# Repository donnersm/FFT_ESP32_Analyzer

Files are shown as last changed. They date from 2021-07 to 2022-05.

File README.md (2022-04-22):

** important update: If your display doesn't respond well to the microphone input, you can adjust resistor R10,( The lower the value, the better the amplification) infact,you can remove it and replace it by a wire or some soldering tin. I did it on my prototype and result is amazing

Also: There are issues with the I2S_DMA_Matric library in version 2.07 ( and maybe above but have not tested) if you experiencing issues with reboot and I2S DMA ERROR.. change this library to version 2.05 (sure to work)

# FFT_ESP32_Analyzer
Spectrum analyzer 8-64channels FFT

8-64 Channel FFT Spectrum Analyzer
-	Line in Audio
-	Mic in Audio
-	8,16,24,32 or 64 channels
-	Different patterns and colors
-	Adjustable Peak Delay time
-	Selectable input filter
-	Auto change of patterns every few seconds ( can be set to on/off)
-	Based on ESP32
-	PCB available with onboard pre-amplifier and connector or HUB75 Displays
-	Can drive ledstrip like WS2812 and similar 
-	Can drive series of HUB75€ Panels
-	Adjustable overall brightness
PCB available with SMD components pre-assembled. You will only need to add the ESP32 board and the connectors / opamp and sockets.
Schematic and PCB layout and gerber files( PCB production files) available
Work in progress:
Future firmware update will include:
-	Smooth LED transition as the LEDS are so fast it will follow the datastream. I want to implement a sort of afterglow on each led when it turns of. That will moving bars will look less hectic.
-	Web interface, I would like to output data on wifi to visualize the spectrum live on a webbrowser. Although technically this already has been done, the challenge will be the use of the ADC's at the same time. Those of you who know the architecture of the ESP32 will now what I mean.
-	Changing the number of bands runtime unlike now it is done before compiling and can only be changed by uploading the firmware with changed parameters.
-	Elaborate and automize the calibration modes.

See Manual4.0.pdf for more details and information

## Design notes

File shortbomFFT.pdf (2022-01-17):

## Page | 9

## 5.1.3. PCB Part list main PCB

## The complete part list for the main PCB is here:

ID | Name | Designator | Footprint | Quantity | Manufacturer Part | Manufacturer | Supplier | Supplier Part
1 | 470uF | C1 | CAP‐SMD_BD8.0‐L8.3‐W8.3‐RD | 1 | VZH471M1CTR‐0810 | LELON | LCSC | C164069
2 | 100nF | C2,C3 | C0805 | 2 | CC0805KRX7R9BB104 | YAGEO | LCSC | C49678
3 | 470uF | C4,C5,C6 | CAP‐SMD_BD8.0‐L8.3‐W8.3‐RD | 3 | VZH471M1CTR‐0810 | LELON | LCSC | C164069
4 | 100nF | C8 | C0805 | 1 | CC0805KRX7R9BB104 | YAGEO | LCSC | C49678
5 | 1uF | C7,C11 | C0805 | 2 | CL21B105KBFNNNE | SAMSUNG | LCSC | C28323
6 | 10nF | C9,C14 | C0805 | 2 | CL21B103KBANNNC | SAMSUNG | LCSC | C1710
7 | 220nF | C10,C15 | C0805 | 2 | CL21B224KBFNNNE | SAMSUNG | LCSC | C5378
8 | 100uF | C12,C16 | C1206 | 2 | 1206X107M6R3NT | FH | LCSC | C178304
9 | 100pf | C13 | C0805 | 1 | CL21C101JBANNNC | SAMSUNG | LCSC | C1790
10 | 22041021 | CN1 | CONN‐TH_22041021 | 1 | 22041021 | MOLEX | LCSC | C185215
11 | 22041051 | CN2,CN3 | CONN‐TH_22041051 | 2 | 22041051 | MOLEX | LCSC | C505160
12 | 22041031 | CN4,P5 | CONN‐TH_3P‐P2.54_22041031 | 2 | 22041031 | MOLEX | LCSC | C293437
13 | Header‐Male‐2.54_1x8 | CN5 | HDR‐TH_8P‐P2.54‐V‐M | 1 | 210S‐1*8P L=11.6MMGold‐plated black | Ckmtw | LCSC | C124381
14 | 22041041 | CN6 | CONN‐TH_22041041 | 1 | 22041041 | MOLEX | LCSC | C185196
15 | ES5JB | D1,D2 | SMB_L4.6‐W3.6‐LS5.3‐RD | 2 | ES5JB | Shandong Jingdao Microelectronics | LCSC | C123908
16 | | P1,P3 | | 2 | WJ500V‐5.08‐2P‐14‐00A | ReliaPro | LCSC | C8465
17 | HDR‐IDC‐2.54‐2X8P | P2 | IDC‐TH_16P‐P2.54_C3406 | 1 | IDC Box 2.54mm 16P Straight | BOOMELE | LCSC | C3406
18 | WJ500V‐5.08‐3P‐14‐00A | P4 | CONN‐TH_3P‐P5.00_WJ500V‐5.08‐3P | 1 | WJ500V‐5.08‐3P‐14‐00A | ReliaPro | LCSC | C72334
19 | 470 | R1,R2 | R0805 | 2 | 0805W8F4700T5E | UniOhm | LCSC | C17710
20 | 470K | R5 | R0805 | 1 | 0805W8F4703T5E | UniOhm | LCSC | C17709
21 | 6.8K | R11 | R0805 | 1 | 0805W8F6801T5E | UniOhm | LCSC | C17772
22 | 10K | R13,R17 | RES‐TH_RK09D1130C2P | 2 | RK09D1130C2P | ALPS Electric | LCSC | C361173
23 | 1K | R15 | R0805 | 1 | 0805W8F1001T5E | UniOhm | LCSC | C17513
24 | 5.1K | R3,R7,R8,R16,R21 | R0805 | 5 | 0805W8F5101T5E | UniOhm | LCSC | C27834
25 | 56K | R19 | R0805 | 1 | 0805W8F5602T5E | UniOhm | LCSC | C17756
26 | 820 | R6,R20 | R0805 | 2 | AC0805FR‐07820RL | YAGEO | LCSC | C229015
27 | 10K | R22,R25 | R0805 | 2 | RNCS0805BKE10K0 | Stackpole Elec | LCSC | C346681
28 | 10K | R9,R23 | RES‐ADJ‐TH_3296W | 2 | 3296W‐1‐103LF | BOURNS | LCSC | C34846
29 | 27K | R10,R24 | R0805 | 2 | 0805W8F2702T5E | UniOhm | LCSC | C17593
30 | 100K | R4,R12,R14,R18,R26,R27 | R0805 | 6 | 0805W8F1003T5E | UniOhm | LCSC | C17407
31 | TC‐1102‐C‐J‐B | SW1,SW2 | KEY‐TH_4P‐L6.0‐W6.0‐P4.50‐LS6.5 | 2 | TC‐1102‐C‐J‐B | XKB Enterprise | LCSC | C381016
32 | 5TR4A 250V | U1 | FUSE‐TH_BD8.5‐P5.08‐D1.0 | 1 | 5TR4A 250V | XC Elec(Shenzhen) | LCSC | C140489
33 | AMS1084CM‐5.0 | U2 | TO‐263‐3_L8.6‐W10.2‐P2.54‐LS14.4‐TL | 1 | AMS1084CM‐5.0 | AMS | LCSC | C56105
34 | ESP32_DevKit_V1_DOIT | U3 | ESP32_DEVKIT_V1_DOIT | 1
35 | 5002 | U4,U6 | TEST‐TH_BD2.54‐P1.39 | 2 | 5002 | Keystone | LCSC | C238123
36 | LM358N | U5 | PDIP‐8_L10.2‐W5.9‐P2.54‐LS7.6‐BL | 1 | LM358N | Texas Instruments | LCSC | C83405
37 | 5001 | U8 | TEST‐TH_BD2.54‐P1.39 | 1 | 5001 | Keystone | LCSC | C238122
38 | 5003 | U9,U10 | TEST‐TH_BD2.54‐P1.39 | 2 | 5003 | Keystone | LCSC | C238124

REMEMBER: MOST COMPONENTS ARE STANDARD COMPONENTS AND CAN BE REPLACED BY OTHER TYPE/ BRAND ETC. USE THIS LIST AS A GUIDE NOT AS AN ABSOLUTE MUST! Everything in red is not assembled when you buy the version with Pre‐assembled SMD. Pos. 35,37,38,13 are optional. Also you should mount U5 and U3 on a socket!
Short bom

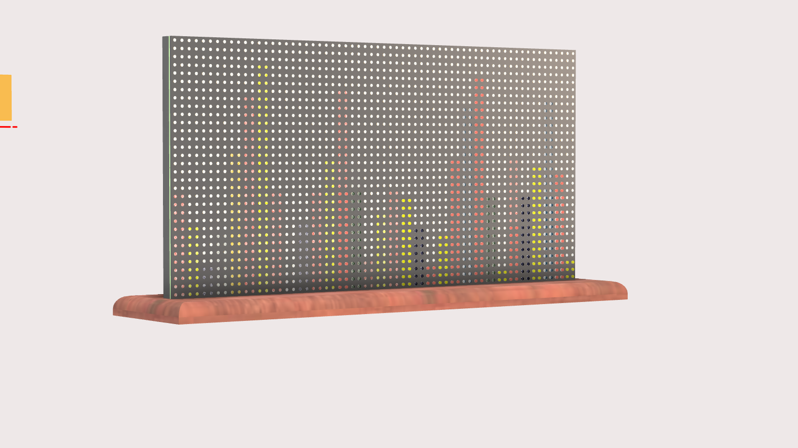
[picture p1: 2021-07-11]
3D Design/Spectrum op plank v7.png

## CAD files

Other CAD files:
3D Design/FFT4.1 on Board.f3d

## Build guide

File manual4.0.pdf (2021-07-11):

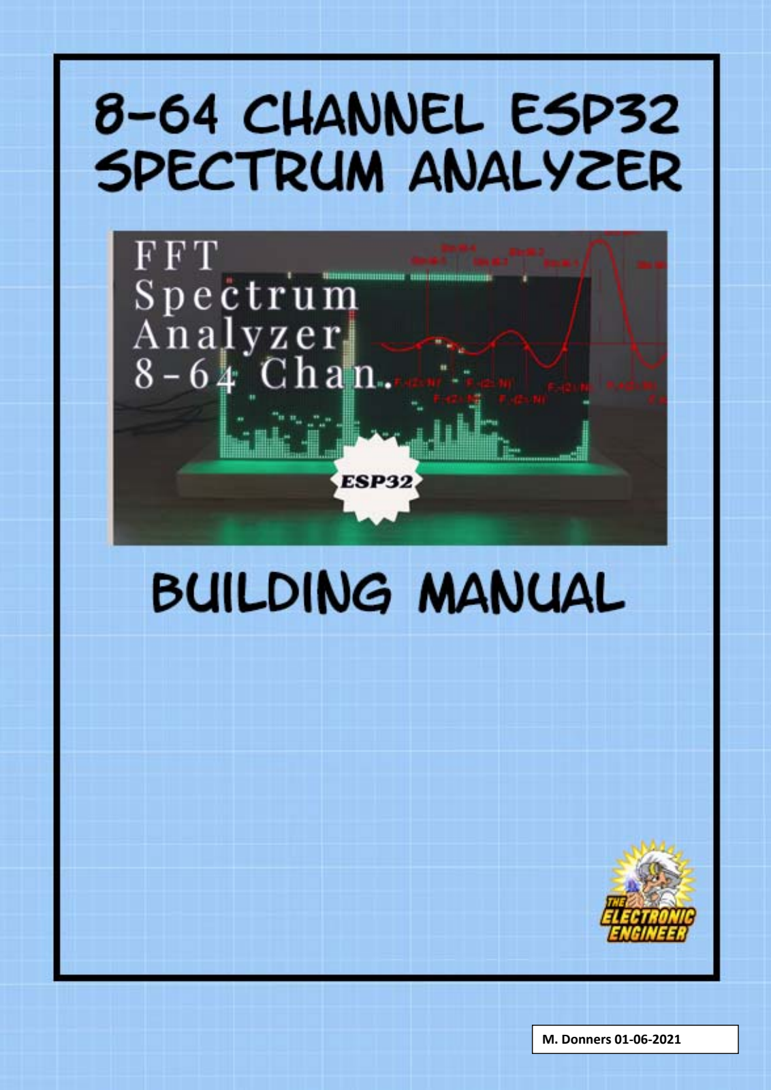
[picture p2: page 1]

M. Donners 01‐06‐2021

## Table of Contents

M Donners Document version 1.0 July 2021

## 1. Disclaimer and safety

I, Mark Donners, The Electronics Engineer, may or may not endorse various Do‐It‐Yourself (DIY) projects and all DIY projects are purely “at your own risk”. As with any DIY project, unfamiliarity with the tools and process can be dangerous. Posts should be construed as theoretical advice only.

If you are at all uncomfortable or inexperienced working on these projects (especially but not limited to electronics and mechanical), please reconsider doing the job yourself. It is very possible (but not likely) on any DIY project to damage belongings or void your property insurance, create a hazardous condition, or harm or even kill yourself or others.

I will not be held responsible for any injury due to the misuse or misunderstanding of any DIY project.

By using the information provided by me, (Website, YouTube, Facebook and other social media), you agree to indemnify me, affiliates, subsidiaries and their related companies for any and all claims, damages, losses and causes of action arising out of your breach or alleged breach of this agreement(disclaimer).

The materials on this site are distributed “as is” and appear on the site without express or implied warranties of any kind, except those required by the relevant legislation. In particular, I make no warranty as to the accuracy, quality, completeness or applicability of the information provided.

The information provided is for entertainment and promotional purposes only. You may not rely on any information and opinions expressed in it for any other purpose.

Disclaimer short version:

This is a DIY project, use any provided information and/or materials at your own risk! I am not responsible for what you do with it!

## 2. About this project

This document is related to the FFT Spectrum analyser. It has 8, 16,24,32 or even 64 frequency bins (channels) and you might be able to double that number of bins if you modify the firmware.

The pcb is capable of driving a matrix of pixelleds ( WS2812 or led matrix) or you can connect one or more HUB75E displays but you will have to make a choice which one to use and adjust the parameters in the settings accordingly.

You can connect your audio signal by using the audio input or you can use the microphone input to connect a small condenser microphone. Although using the microphone will limit the frequency response because of its limitations.

The input sensitivity is automated and it will adjust to the levels off the input. You can adjust brightness and peak hold time. When it does not receive any input signal, after a while, it will go to fire mode in which some leds/display will light up like a fire.

I used two HUB75E panels for my prototype as I mounted them on a wooden stand. The PCB was mounted to the back of the display. I designed a PCB for the electronics. The PCB can be purchased at my Tindie web shop. The firmware (Arduino Sketch ) is open source and you can modify it to your needs.

## 3. Operation

You can use the microphone in to connect a small condenser microphone or you can connect your audio device to the line input connectors.

Mode button
The mode button has 3 functions:

Short press: change pattern(mode), there are 12 available patterns from which the last one is a fire screensaver.

Fast double press: Change the calibration filter. You can choose from none, white, pink or brown noise. Each mode will manipulate the output data accordingly.

For white noise, a white noise sound source of 1Vpp was connected to the input and all the output values where measured. The measured values where recalculated and copied to the filter database. When calibrated, all the output values are almost equil in amplitude when the mentioned source is connected. I did the same for pink and brown noise.

Long press: Press and hold for a few seconds to enable/disable the automode. When automode is enabled, the patterns will change every few seconds.

Reset Button
This will reset the microcontroller. However, It will not reset the led strips.

Brightness Potmeter
You can use this to adjust the overall brightness of all leds / display. WARNING:Make sure you use a power supply to match the current for the brightness that you set. For sure, the ESP32 onboard regulator can not handle all leds at full brightness. It is best to use an external powersupply that can handle 4 to 6 A. If you are using the USB cable that is connected to the ESP32, you might end up with a burning sensation coming from the ESP32 Board.

Peak Delay Potmeter
You can use this to adjust the time it takes for a peak to fall down to the stack

Serial Monitor
If you enabled the DEBUG mode in the firmware of by activating and completing the hardware test, the serial monitor (USB) will output information.

4. Tools needed.

You will be working with low voltage and you should know your way around basic electronics. Using the wrong voltage or polarity might not kill you but it will destroy your project in an instance!

Being successful in building this device requires some adequate skills and tools. You should be able to solder small components on a PCB which will require a soldering station with a small tip as you will be handling components like 0805 sized although small, if you have a steady hand, you should be able to solder them onto the board. If this is beyond your possibilities, then you should buy the pcb version that has all SMD components pre‐installed.

Furthermore, you will be programming the microcontroller by using the Arduino IDE environment. Although the steps to do so will be described in this document, it is advisable for you to get to know this Arduino software.

And yes, you will need some basic tools like a screwdriver

## 5. Hardware

## 5.1. Main PCB

The pcb is available at my Tindie store here:

https://www.tindie.com/products/markdonners/pcb‐8‐64‐channel‐fft‐spectrum‐analyzer/

The PCB has all SMD components pre‐installed and all you nee to add is the ESP32 board and a hand full of small components.

Shipping is only possible within the EU because shipping to other countries will involve import Tax, declarations of conformity and other complicated stuff. Nobody is looking for that kind of complicated formalities or import tax upon receiving the goods. I do make some exceptions for USA and UK. If you are a resident of a country that I don’t ship to, you can always order a pcb directly from a PCB supplier near you. The Gerber productions files you need for that are available for download, although it might be more expensive than what you are hoping for. If you need 1 or 2 PCB’s, a Tindie order is the cheapest way to go.

My shipping policy might change over time so always check the Tindie store to see if I am shipping to your country. ADDITION: I have successfully shipped to UK, USA and other non‐EU countries but handling the tax, import fee and so on is on you! Check out the Tindie store to see what is possible for your country.

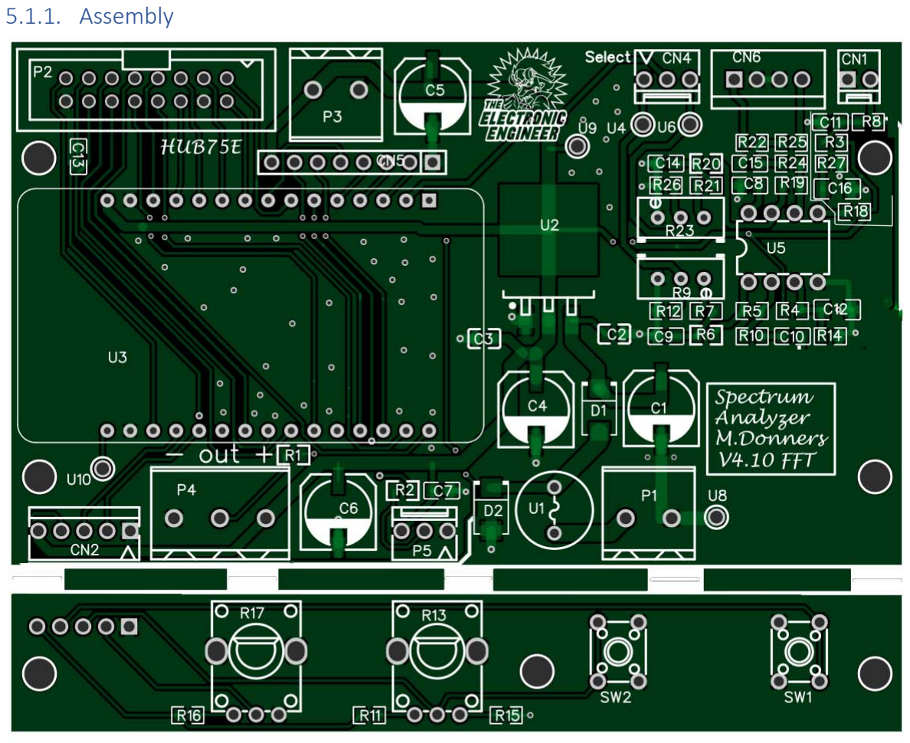
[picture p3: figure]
5.1.1. Assembly

Assembly notes:

Start with all small SMD components. The last smd components to be mounted are C1,C4,C5 and C6.

Use IC Sockets or Female headers to mount Ic's (U5), ESP32 board (U3).It is also wise to use a socket for the fuse (U1). Solder all the connectors last. You don’t need to solder the connectors that you don't need. Connector CN5 is only needed if you are planning to use those extra pins but if not, you can leave it out. Connectors P2 and P3 are to be used to connect a HUB75E panel while connector P4 is used for connecting ledstrips or a pixel‐led based matrix. You can decide to leave out the connectors you do not need.

C13 has been added to compensate Latency Timing for some versions of the board I run into in a shipment from May 2021.

Here are some links for some of the used components. A more detailed list of components is available on one of the following pages of this document.

Microphone
A used a simple electret microphone like this one:

https://nl.aliexpress.com/item/32961327636.html?spm=a2g0o.productlist.0.0.40156749GH0jMh&algo_pvid=b3873d4e‐2d66‐4844‐b423‐45a81e07bc15&algo_expid=b3873d4e‐2d66‐4844‐b423‐ 45a81e07bc15‐
0&btsid=2100bdd516132465203027466e5419&ws_ab_test=searchweb0_0,searchweb201602_,sear chweb201603_

Power Supply

You will be needing a power supply of DC 12V that can handle 4 to 6A. ( Current depends on the number of panels or leds you are planning to connect. Make sure your power supply is stable and doesn’t have noise on the output.

You'll also need some connectors for audio and power, a toggle switch to select the audio input and some wire to connect all. Regarding the power to the leds, use a wire that can handle a current of 4A Depending on what you planning, thinner wire can do the job as well.

Also, you'll need to order a few meter of Pixel Ledstrip WS2812. Make sure you order the one that works with your design. (number of pixels per meter varies) I used 74Leds/meter version.

Or are you planning to use one or more HUB75 led panels? I used 2 64*64 panels to create a matrix of 64 pixels height and 128 pixels width.

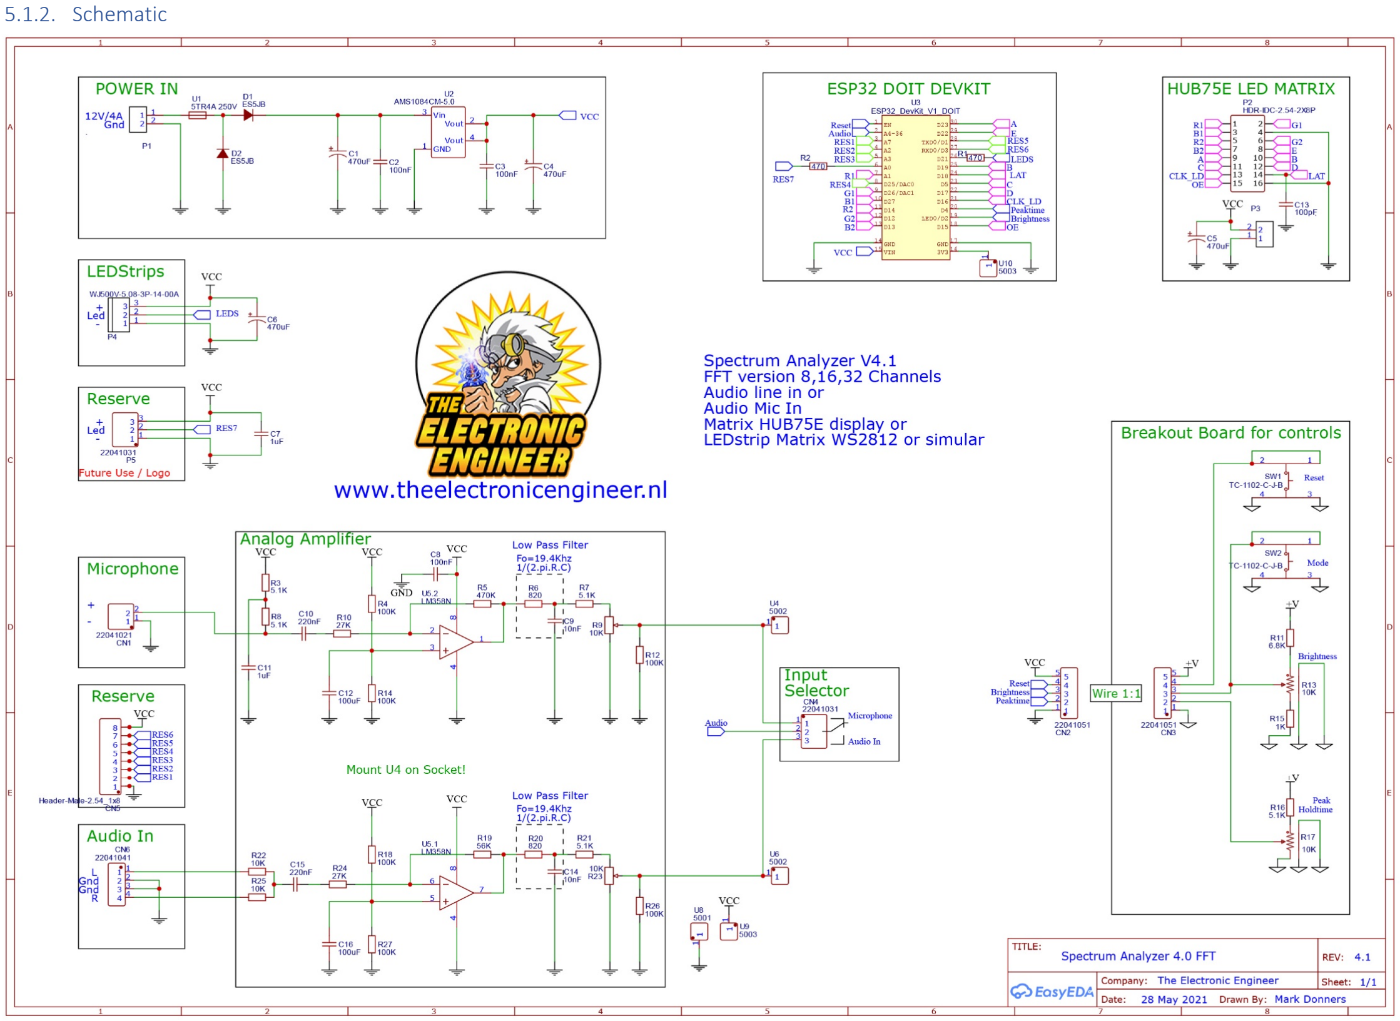
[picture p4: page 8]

Page | 8
5.1.2. Schematic

5.1.3. PCB Part list main PCB
The complete part list for the main PCB is here:
ID | Name | Designator | Footprint | Quantity | Manufacturer Part | Manufacturer | Supplier | Supplier Part
1 | 470uF | C1 | CAP‐SMD_BD8.0‐L8.3‐W8.3‐RD | 1 | VZH471M1CTR‐0810 | LELON | LCSC | C164069
2 | 100nF | C2,C3 | C0805 | 2 | CC0805KRX7R9BB104 | YAGEO | LCSC | C49678
3 | 470uF | C4,C5,C6 | CAP‐SMD_BD8.0‐L8.3‐W8.3‐RD | 3 | VZH471M1CTR‐0810 | LELON | LCSC | C164069
4 | 100nF | C8 | C0805 | 1 | CC0805KRX7R9BB104 | YAGEO | LCSC | C49678
5 | 1uF | C7,C11 | C0805 | 2 | CL21B105KBFNNNE | SAMSUNG | LCSC | C28323
6 | 10nF | C9,C14 | C0805 | 2 | CL21B103KBANNNC | SAMSUNG | LCSC | C1710
7 | 220nF | C10,C15 | C0805 | 2 | CL21B224KBFNNNE | SAMSUNG | LCSC | C5378
8 | 100uF | C12,C16 | C1206 | 2 | 1206X107M6R3NT | FH | LCSC | C178304
9 | 100pf | C13 | C0805 | 1 | CL21C101JBANNNC | SAMSUNG | LCSC | C1790
10 | 22041021 | CN1 | CONN‐TH_22041021 | 1 | 22041021 | MOLEX | LCSC | C185215
11 | 22041051 | CN2,CN3 | CONN‐TH_22041051 | 2 | 22041051 | MOLEX | LCSC | C505160
12 | 22041031 | CN4,P5 | CONN‐TH_3P‐P2.54_22041031 | 2 | 22041031 | MOLEX | LCSC | C293437
13 | Header‐Male‐2.54_1x8 | CN5 | HDR‐TH_8P‐P2.54‐V‐M | 1 | 210S‐1*8P L=11.6MMGold‐plated black | Ckmtw | LCSC | C124381
14 | 22041041 | CN6 | CONN‐TH_22041041 | 1 | 22041041 | MOLEX | LCSC | C185196
15 | ES5JB | D1,D2 | SMB_L4.6‐W3.6‐LS5.3‐RD | 2 | ES5JB | Shandong Jingdao Microelectronics | LCSC | C123908
16 | | P1,P3 | | 2 | WJ500V‐5.08‐2P‐14‐00A | ReliaPro | LCSC | C8465
17 | HDR‐IDC‐2.54‐2X8P | P2 | IDC‐TH_16P‐P2.54_C3406 | 1 | IDC Box 2.54mm 16P Straight | BOOMELE | LCSC | C3406
18 | WJ500V‐5.08‐3P‐14‐00A | P4 | CONN‐TH_3P‐P5.00_WJ500V‐5.08‐3P | 1 | WJ500V‐5.08‐3P‐14‐00A | ReliaPro | LCSC | C72334
19 | 470 | R1,R2 | R0805 | 2 | 0805W8F4700T5E | UniOhm | LCSC | C17710
20 | 470K | R5 | R0805 | 1 | 0805W8F4703T5E | UniOhm | LCSC | C17709
21 | 6.8K | R11 | R0805 | 1 | 0805W8F6801T5E | UniOhm | LCSC | C17772
22 | 10K | R13,R17 | RES‐TH_RK09D1130C2P | 2 | RK09D1130C2P | ALPS Electric | LCSC | C361173
23 | 1K | R15 | R0805 | 1 | 0805W8F1001T5E | UniOhm | LCSC | C17513
24 | 5.1K | R3,R7,R8,R16,R21 | R0805 | 5 | 0805W8F5101T5E | UniOhm | LCSC | C27834
25 | 56K | R19 | R0805 | 1 | 0805W8F5602T5E | UniOhm | LCSC | C17756
26 | 820 | R6,R20 | R0805 | 2 | AC0805FR‐07820RL | YAGEO | LCSC | C229015
27 | 10K | R22,R25 | R0805 | 2 | RNCS0805BKE10K0 | Stackpole Elec | LCSC | C346681
28 | 10K | R9,R23 | RES‐ADJ‐TH_3296W | 2 | 3296W‐1‐103LF | BOURNS | LCSC | C34846
29 | 27K | R10,R24 | R0805 | 2 | 0805W8F2702T5E | UniOhm | LCSC | C17593
30 | 100K | R4,R12,R14,R18,R26,R27 | R0805 | 6 | 0805W8F1003T5E | UniOhm | LCSC | C17407
31 | TC‐1102‐C‐J‐B | SW1,SW2 | KEY‐TH_4P‐L6.0‐W6.0‐P4.50‐LS6.5 | 2 | TC‐1102‐C‐J‐B | XKB Enterprise | LCSC | C381016
32 | 5TR4A 250V | U1 | FUSE‐TH_BD8.5‐P5.08‐D1.0 | 1 | 5TR4A 250V | XC Elec(Shenzhen) | LCSC | C140489
33 | AMS1084CM‐5.0 | U2 | TO‐263‐3_L8.6‐W10.2‐P2.54‐LS14.4‐TL | 1 | AMS1084CM‐5.0 | AMS | LCSC | C56105
34 | ESP32_DevKit_V1_DOIT | U3 | ESP32_DEVKIT_V1_DOIT | 1
35 | 5002 | U4,U6 | TEST‐TH_BD2.54‐P1.39 | 2 | 5002 | Keystone | LCSC | C238123
36 | LM358N | U5 | PDIP‐8_L10.2‐W5.9‐P2.54‐LS7.6‐BL | 1 | LM358N | Texas Instruments | LCSC | C83405
37 | 5001 | U8 | TEST‐TH_BD2.54‐P1.39 | 1 | 5001 | Keystone | LCSC | C238122
38 | 5003 | U9,U10 | TEST‐TH_BD2.54‐P1.39 | 2 | 5003 | Keystone | LCSC | C238124

REMEMBER: MOST COMPONENTS ARE STANDARD COMPONENTS AND CAN BE REPLACED BY OTHER TYPE/ BRAND ETC. USE THIS LIST AS A GUIDE NOT AS AN ABSOLUTE MUST!

5.2. Electronics explained.

The Electronics can be divided into several sections. Of course, there is a power supply and some standard connectors for audio input and power and there are a few standard switches. Nothing scary about that at all.

Connector P1 is used to connect a 12V power supply. The circuit is protected by a fuse and two power diodes. If the power is connected reversed, D2 will conduct so that the current will rise beyond the capabilities of the fuse. While D1 will protect the circuit from this reversed voltage, the fuse will blow. However, under normal circumstances, the power source is connected correctly and while passing a few capacitor to smooth out any power supply noise or instabilities, the 12V is offered to the on board regulator U2. U2 converts the 12V power to 5V and feeds the ESP32 board and some of our onboard features like the pre‐amplifier, the led strip or matrix display.

The user interface consists of 2 potentiometers and two switches. The potmeters control brightness and Peak time delay while the switches are used to set mode, filter and auto‐change mode or to give a system reset. To save out on IO on the ESP32, switch SW2 and potmeter R13 are combined in on circuit. When ever the switched is pressed, the voltage on this I/O line will be 0V (gnd) but when not pressed, the voltage on the I/O line will be between 0.3V and 3V, depending on the setting of the potmeter. This makes it possible to use 1 I/O input for both the potmeter and switch at the same time.

The PCB has room for a dual pre‐amplifier. One can be used to connect a microphone and the other can be used for the line in. You have to set a jumper or use a toggle switch connected to CN4 to select which input you want to use.

Both amplifier use a low pass filter to keep the upper frequencies away from the microcontroller. Except from the microphone offset that is created with R3 and R8, both circuits are the same. Below is a diagram of the frequency response for both circuits. Although the frequency response of the amplifier looks promising, the microphone will be the frequency limiting factor. That is why you can expect better frequency bandwidth from the line input.

In regards to the HUB75 panels that are connected to P2, C3 has an important function. In May 2021, I received a batch on HUB75E panels that uses a mix of chipsets and we had a lot of trouble to get them to respond properly without glitches. Without C3 this was nearly impossible. C3 is connected to the LATENCY pin and slows down the flanks of the LATENCY Pulse. Also, the length and quality of the flatcable, used to connect the panel to the pcb should be as short as possible! C3 is 100pF in my setup but, depending on the length of the flatcable, you might want to change that. However, maybe you have more luck than me and you’ll receive a whole different batch that has no problem whatsoever.

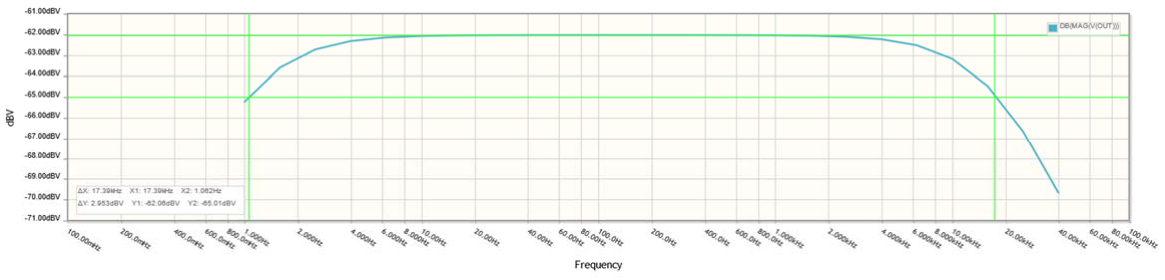
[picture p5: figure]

‐3db@ 1Hz and 20Khz

## 5.3. Visualisation

You can select 1 of 2 option for visualizing the spectrum data. You have to make a selection in the settings panel of the Arduino sketch to match your setup. You can use WS2812 or similar ledstrips/Matrix or you can use HUB75 displays.

5.3.1. Using one or more HUB75E Panels
You can connect several panels together to increase the height or width of your matrix. In my prototype, I used two 64x64 HUB75E panels. So the height of my matrix was 64 pixels and the width was 128. Depending on the type of HUB75 display you are using, you might have to change some of the parameters to get it to work correctly. Also note that it is not likely that two panels with different chipset will work together. If you need more info on how and what, regarding these panels, take a look at the github of the driver, all info ( and driver) is here:

mrfaptastic/ESP32‐HUB75‐MatrixPanel‐I2S‐DMA: An Adafruit GFX Compatible Library for the ESP32 to drive 64x32px or 64x64px HUB75 LED matrix modules using the ESP32 DMA Engine for faster refresh rates. Supports panel chaining. (github.com)

The following settings apply to the use of this panel:

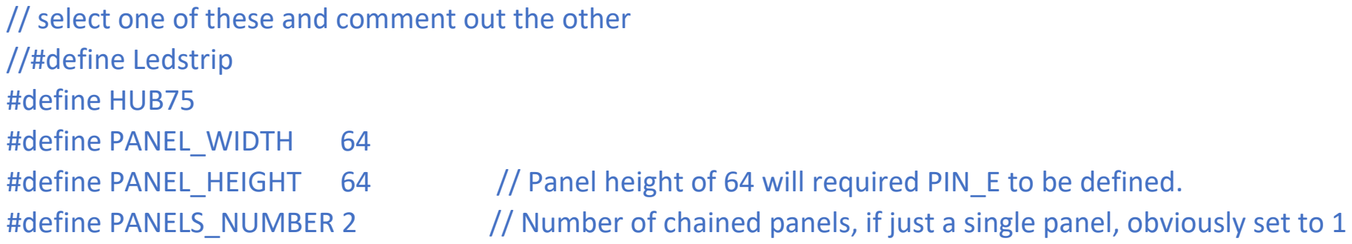
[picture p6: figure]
//#define Ledstrip #define HUB75; #define PANEL_WIDTH

5.3.2. Using a Pixeled Matrix ( WX2812 based or similar)
The software was tested with two Led Matrixes that where connected together. Each matrix has a dimension of 16x16 pixels so the led matrix I tested with was 16 pixels in height and 32 pixels wide. Remember that the more leds you use, the slower the matrix will be. If the matrix is too big, it will react visibly slow.

You can tell the firmware how your ledmatrix is configured by changing the following parameters

see https://github.com/marcmerlin/FastLED_NeoMatrix for Tiled Matrixes, Zig‐Zag and so forth

LEDDRIVER.H

// select one of these and comment out the other

LEDDRIVER.H

// select one of these and comment out the other

#define PANEL_HEIGHT | 64 | // Panel height of 64 will required PIN_E to be defined.

#define PANELS_NUMBER 2 | // Number of chained panels, if just a single panel, obviously set to 1

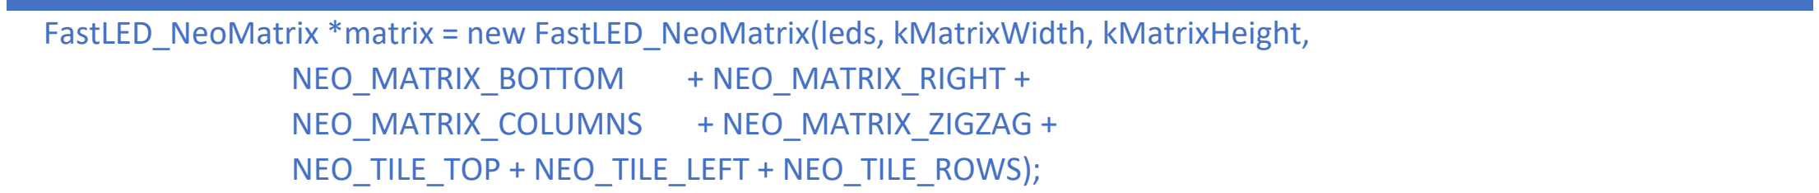
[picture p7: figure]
NEO_MATRIX_BOTTOM; + NEO_MATRIX_RIGHT +

FastLED_NeoMatrix *matrix = new FastLED_NeoMatrix(leds, kMatrixWidth, kMatrixHeight,

NEO_MATRIX_COLUMNS + NEO_MATRIX_ZIGZAG + NEO_TILE_TOP + NEO_TILE_LEFT + NEO_TILE_ROWS);

If your ledstrip are lighting up in the wrong direction or if there is a difference between odd and even rows, this is these are the settings you need to adjust.

If you are using this PCB to replace the older PCB design with frequency board and MSGEQ7's and you see that the directions of the ledstrips is zigzag and left /right side are exchanged, try this:

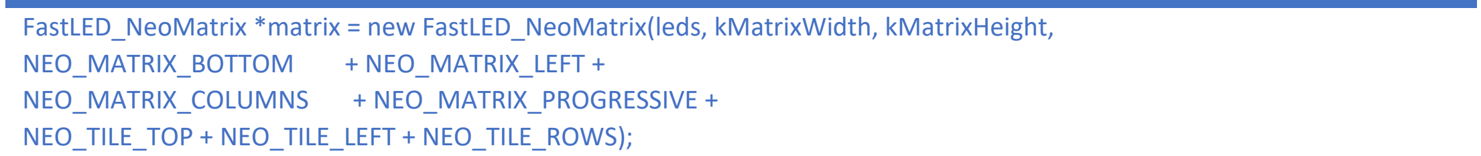
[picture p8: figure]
NEO_MATRIX_BOTTOM; + NEO_MATRIX_LEFT +

Some more settings that effect the use of ledstrips are the following:

## 5.4. Wiring

The wiring is not that difficult. The wiring diagram is shown on the next page.

I used shielded wire to connect the microphone and the audio input and I used some general wire for everything else.

Give some extra attention to the power lines that feed the LED Strips. You must wire the data lines in series, meaning that the data out of one strip will be connected to the data in of the next. Etc. You can also do that with the power lines, but I would not recommend that. It is better to feed each strip with its own power. This will keep the current trough the power line limited for each wire and it will better distribute the power to all leds.

5.4.1. HUB75E display wiring
If you are using HUB75 Panels, make sure to use a decent flatcable and keep it's length as short as possible. Simple connect the flatcable to the PCB and display and don't forget to connect the powerline. Be warned: If you are using a large panel or several at at the same time, the on board 5V connecter shouldn't be used. Wire the panel directly to a 5V supply instead.
5.4.2. Main LEDSTRIPS / Matrix wiring
The ledstrips or matrix is connected using three wires only, gnd, +5V and the data line.

FastLED_NeoMatrix *matrix = new FastLED_NeoMatrix(leds, kMatrixWidth, kMatrixHeight,

NEO_MATRIX_COLUMNS + NEO_MATRIX_PROGRESSIVE +
NEO_TILE_TOP + NEO_TILE_LEFT + NEO_TILE_ROWS);

// Ledstrip settings
#define CHIPSET | WS2812B | // LED strip type

#define LED_PIN | 21 | // LED strip data Pin, only change if you use different hardware

#define SERPENTINE | false | // Set to false if you're LEDS are connected end to end, true if serpentine

#define COLOR_ORDER | GRB | // If colours look wrong, play with this

#define LED_VOLTS | 5 | // Usually 5 or 12

#define MAX_MILLIAMPS | 2000 | // Careful with the amount of power here if running off USB port

const uint8_t kMatrixWidth = | 32; | // Matrix width ‐‐> number of columns in your led matrix
const uint8_t kMatrixHeight = | 16; | // Matrix height ‐‐> number of leds per colum

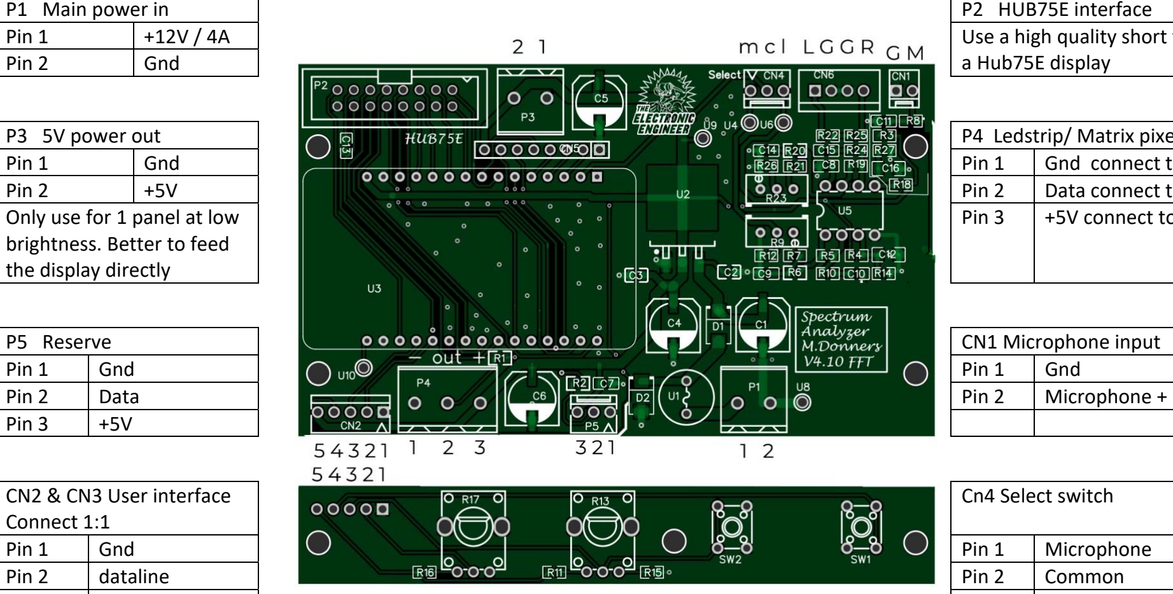
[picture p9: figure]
Pin 2; Gnd; a Hub75E display; Only use for 1 panel at low brightness. Better to feed the display directly; P5 Reserve; CN1 Microphone input; Pin 1; Data; Microphone +; Pin 3; CN2 & CN3 User interface Connect 1:1; Cn4 Select switch; Microphone; dataline; Common

Page | 13

## 5.5. Wiring tables

The wiring is not that spectacular.

P1 Main power in | P2 HUB75E interface
Pin 1 | +12V / 4A | Use a high quality short flatcable to connect
P3 5V power out | P4 Ledstrip/ Matrix pixel leds
Pin 1 | Gnd | Pin 1 | Gnd connect to gnd pin ledstrip
Pin 2 | +5V | Pin 2 | Data connect to data input ledstrip
| | Pin 3 | +5V connect to power pin ledstrip
Pin 3 | dataline | Pin 3 | Line in
Pin 4 | dataline | You can use a toggle switch or make a
Pin 5 | +5V | permanent selection using a jumper

CN6 Line In
Pin 1 | Left Channel
Pin 2 | Gnd
Pin 3 | Gnd
Pin 4 | Right channel

## 6. Software

In general you can say that the program in running in repeated mode. Every loop, it will process data from a buffer using FFT. The buffer itself if filled with data in the background while the main program is running by using I2S direct communication. One of the perks of the ESP32. The FFT data is analysed and grouped into bars that are displayed. The ledstrip/matrix is controlled with a fastled library while the HUB75 display is driven using another great library with I2S approach. Each bar represents a frequency band and the code calculated the number of leds it should light up per bar. If the number of 'new' LEDS is lower than the number of LEDS that are currently on, it will initiate a dropping of the top light. The speed it used to drop is adjustable by a variable resistor. There is also a variable resistor to adjust the brightness of the LEDS. This brightness is limited in the software because a maximum brightness of all 280 LEDS being activated at the same time, could result in a very high current. The current input is limited by a 4A fuse. The traces on the PCB are not calculated for a higher current.

The unit has two switches, one to do a reset and one to change the operating mode. (Changing colours and patterns)

Although the ESP32 has a dual core and one can assign functions to a specific core, it is not used in this version because it is not needed. Although, that might change in the future when more functions are implemented. ( for example a web interface)

## 6.1. Files

The firmware can be divided into 9 files

- FFT_ESP_V1.0 → main function and code
- FFT.h → Sepcifications and settings for the FFT functions
- I2SPlUGIN.h → Initialisation of the on board I2S audio functions
- LEDDRIVER.h → Settings that are specific for HUB75E and/or Ledstrip
- PatternsHUB75.h → All the graphic patterns specific for HUB75
- PatternsLedstrip.h → All the graphic patterns specific for Ledstrip
- Settings.h → All settings
- Fire.h → code for fire screensaver
- Logos.h → contains the logo data of The Electronic Engineer

# You can download the latest sketch here:

# https://github.com/donnersm/FFT_ESP32_Analyzer

6.1.1. Settings
The following settings can be changed. The name in the top of each table gives the name of the file where to find it.

For Ledstrip and HUB75 settings see section 5.3

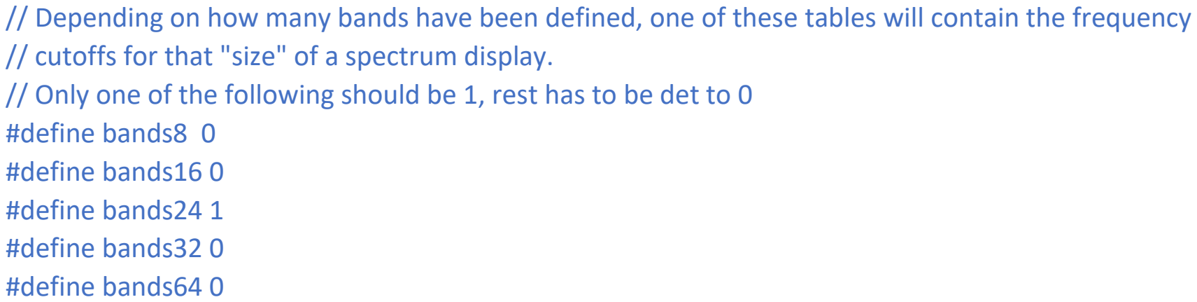
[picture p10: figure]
#define bands8 0 #define bands16 0 #define bands24 1 #define bands32 0 #define bands64 0

// Depending on how many bands have been defined, one of these tables will contain the frequency // cutoffs for that "size" of a spectrum display.
// Only one of the following should be 1, rest has to be det to 0

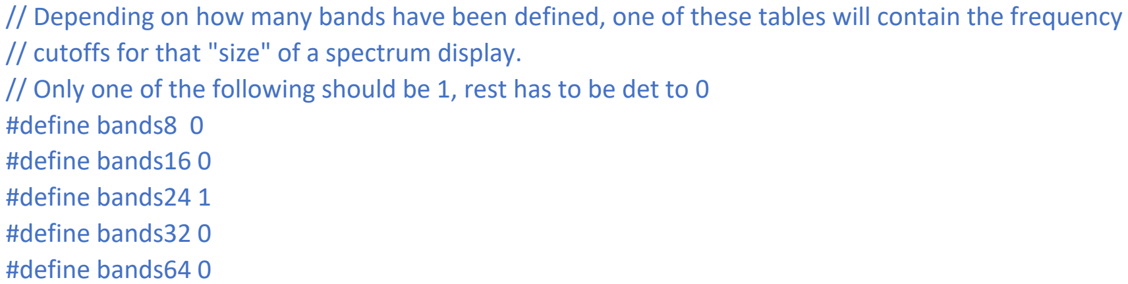
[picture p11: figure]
#define bands8 0 #define bands16 0 #define bands24 1 #define bands32 0 #define bands64 0

// Depending on how many bands have been defined, one of these tables will contain the frequency // cutoffs for that "size" of a spectrum display.
// Only one of the following should be 1, rest has to be det to 0

// Debug features should default be off!
#define PrintRAWBins | 0 | // set to 1 if you want to print the RAW FFT BIN values of each pass to the serial port

#define PrintADCRAW | 0 | // Set to 1 if you want to print the RAW ADC Values's of each pass to the serial port‐‐> that

// is a lot of samples!!
#define VisualizeAudio | 0 | // Sends the raw ADC values from buffer to serial plotter...that is a lot of data!!

#define CalibratieLog | 0 | // a tool tell help with calibrating to noise input signal

int DEBUG = | 0 ; | // When debug=1, extra information is printed to serial port. Turn of if not needed
#define DEBUG_BUFFER_SIZE 100 | // Debug buffer size

//Options Change to your likings
#define BottomRowAlwaysOn 1 | // if set to 1, bottom row is always on. Setting only applies to LEDstrip not HUB75

#define Fallingspeed | 5 | // Falling down factor that effects the speed of falling tiles

#define LogoBoot | 1 | // Show logo on boot when set to 1, only works in combination with HUB75

int Peakdelay = | 60; | // Delay before peak falls down to stack. Overruled by PEAKDEALY Potmeter
#define GAIN_DAMPEN | 2 | // Higher values cause auto gain to react more slowly

#define SecToChangePattern 10 | // number of seconds that pattern changes when auto change mode is enabled

#define MAX_VU | 5000 | // How high our VU could max out at. Arbitarily tuned.

int buttonPushCounter = | 0; | // This number defines what pattern to start after boot (0 to 12)
bool autoChangePatterns = | false; | // After boot, the pattern will not change automatically.
int NoiseTresshold = | 1500; | // this will effect the upper bands most.
#define DemoAfterSec | 6000 | // if no input signal during this number of milli seconds, the unit will go to demo mode

#define DemoTreshold | 500 | // this defines the treshold that will get the unit out of demo mode

#define BRIGHTNESSMAX | 255 | // Max brightness of the leds...carefull...to bright might draw to much amps!

int BRIGHTNESSMARK= | 50; | // Default brightnetss, however, overruled by the Brightness potmeter
int BRIGHTNESSMIN = | 20; | // Min brightness

//buttonstuf don't change unless you know what you are doing
#define ShortPress | 45

#define LongPress | 2000

#define LongerPress | 4000

#define ButtonTimeout | 200

#define ButtonSequenceRepeatTime 200

// There are also several setting for the different colors that are used in the patterns. You can change them and experiment

## 7. Programming your Arduino

I used the Arduino IDE. It is freely available online and it does the job. However, I recently stumbled on something called Sloeber Beryllium which is a great tool that offers a much better compiler interface. However, it has a bit of a learning curve but I promise, it's worth it! Why don't you check it out? You can also use Visual Studio or some other great IDE. However, it is important the right library and it is best not to install what you don't need as it might give you errors when compiling. Make sure that your Arduino IDE is set for using the ESP32. If you don't know how to do so, google or look it a youtube video. There are some very clear instructions and setting up the IDE is not hard. You can do it! In a nutshell, it comes down to this:

1. In the Ide preferences window, look for the line: Additional Boards Manager and add the following line; https://dl.espressif.com/dl/package_esp32_index.json
2. Go to your board manager and look for ESP32 and install the ESP32 from Espressif Systems.
3. Select the correct board before you compile and you are good to go

## 7.1. Here a few libraries that you'll need for sure:

Here are the libraries that you will need to install using the Arduino Library manager. These I the versions I used. Higher version might work just fine.

Adafruit_BusIO | at version 1.7.1
Adafruit_GFX_Library | at version 1.10.4
arduinoFFT | at version 1.5.6
ESP32_HUB75_LED_MATRIX_PANEL_DMA_Display | at version 2.0.5
FastLED | at version 3.4.0
FastLED_NeoMatrix | at version 1.1
Framebuffer_GFX | at version 1.0

Remark: I had some trouble compiling when I started. Turned out that Arduino IDE had many libraries activated and it decided to choose the wrong ones whenever it had to choose between libraries. I solved it by uninstalling the Arduino IDE and re‐installing it from scratch.

## 8. Trouble shooting and a word of thanks

No trouble so far! Will be added one at a time in time

Or as Dave Plummer would say from Dave's Garage: In the meantime and in between time…catch you later next time.

Don't forget to check out his channel as he inspired me to make this build as did many others:

Dave Plummer | https://www.youtube.com/channel/UCNzszbnvQeFzObW0ghk0Ckw
Mrfaptastic | https://github.com/mrfaptastic
Scott Marley | https://www.youtube.com/user/scottmarley85
Brian Lough | https://www.youtube.com/user/witnessmenow
atomic14 | https://www.youtube.com/channel/UC4Otk‐uDioJN0tg6s1QO9lw

You probably got hands on this document as a result of watching a video on my youtube channel, right?

Well, if you did, I would appreciate a like, a subscribe and a comment if you like. Feedback and pat on the shoulder is what keeps me going and it motivates me to put more stuff in the public domain.

https://www.youtube.com/channel/UCm5wy‐2RoXGjG2F9wpDFF3w

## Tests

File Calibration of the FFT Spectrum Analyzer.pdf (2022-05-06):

Calibration of the FFT Spectrum Analyzer.

This example applies to 8 bands but for other bands, the procedure is the same.

1. Enable the calibration log by changing the following setting in the settings.h
a. #define CalibratieLog 0 → change to 1
2. Compile and upload to your ESP32
3. Open the Serial monitor to see what going on.
4. Make sure the Analyzer is running with settings FILTER: NONE. You can change it by fast double clicking the mode button.
5. Hook up a audio source to the line in that is able to play noise. You could use your computer for that. However, keep in mind that ground loops can be a buzz killer here. If your computer is already hooked up with the usb cable then you might consider hooking up the audio without ground. Try what gives you the best result.
6. Set the volume to what you think is acceptable, you can always change it later. I set the volume of my pc to max while using the line out of the computer.
7. Now, play the noise pattern you want to calibrate. For example white noise.
8. Wait a few runs, then clear your serial monitor window and wait for the next calibration output. It should look like this:
a. BandCalibration_XXXX[8]= { 1.00, 2.77, 3.09, 3.37, 3.96, 4.01, 4.02, 4.52};
If your analyzer is using more channels, the more numbers this line will have. (8,16,24,32 or 64)
9. In the FFT.h tab in your sketch, find the following lines
static double BandCalibration_Pink[8]=
{ 4.08, 1.56, 1.00, 2.80, 3.23, 3.63, 6.19, 1.65 }; static double BandCalibration_White[8]=
{ 25.84, 3.43, 1.10, 2.95, 3.37, 3.39, 5.46, 1.00 };
static double BandCalibration_Brown[8]=
{ 2.72, 1.17, 1.00, 3.34, 4.83, 5.57, 11.18, 3.08 };
10. As we calibrated with white noise, these calibration values should be applied to the White values:
a. static double BandCalibration_White[8]= { 25.84, 3.43, 1.10, 2.95, 3.37, 3.39, 5.46, 1.00 };
b. Now replace this line with the line you copied from the serial window
c. BandCalibration_XXXX[8]= { 1.00, 2.77, 3.09, 3.37, 3.96, 4.01, 4.02, 4.52};
d. Rename it to: BandCalibration_White[8]= { 1.00, 2.77, 3.09, 3.37, 3.96, 4.01, 4.02, 4.52};
11. This concludes the calibration. Don’t forget to change the CalibratieLog to 0 because the calculation of the calibration value and printing them comes at the price of speed. Now compile and upload.
12. Now, with the noise source still hooked up to your system, after the upload is done and the unit is playing, double press the mode button until you see FILTER: WHITE. It will now use your calibrated values.
13. Do the same for all the other filters if you like.

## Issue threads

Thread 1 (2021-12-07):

Little to no response on display when using microphone input

donnersm, 2021-12-07:
The amplitude of most mics is to low. You can remove R10 and replace it by a wire or a resistor with a lower value.
On my prototype, I replaced it with a jumper by adding a drop of soldering tin where the resistor use to be.
Now, the microphone response is amazing

Closed 2021-12-07.

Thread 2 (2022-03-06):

I2S dma errors & pcb suggestions

Ultrawipf, 2022-03-06:
Regarding the software i am not able to get it working and spent some time debugging without any results yet:
After one iteration of the mainloop the chip hangs and does not read another sample buffer after the first buffer is processed.
In the serial terminal on every call to the i2s_adc_enable or i2s_adc_disable function it will print a dma error: "I2S: dma error, interrupt status: 0x00002000"

The led matrix is set as a 2x64x64, hub75 enabled, i2s SAMPLEBLOCK = 1024 as default with 2 dma buffers and a sample rate of 44.1kHz.
Increasing the amount of dma buffers to 4 for example will process 3 buffers before it hangs.
The ADC data itself looks valid.

Regarding the PCB design i have a few suggestions of things i noticed while assembling:

If it is intended for the led matrix to be driven by the board i would replace the LDO with a switch mode converter or leave out the power input side completely and expect a regulated 5V input to just pass through.
The expected currents are way too high for a linear regulator and the diode drop will be significant as well resulting in very poor efficiency and high heat at those currents expected by a larger panel. I am completely bypassing the power input section with a fixed 5V PSU.

The analog circuitry should probably be supplied by 3.3V either via a separate LDO or the ESP32 onboard one so it safely clips to 3.3V reducing the need for resistors as there are also a lot of unique resistors and capacitors that may be possible to combine reducing the complexity.

Maybe i misinterpreted some design decisions but thats probably how i would have designed it.

donnersm, 2022-03-06:
Hi Yannick,

Thanks for you feedback, I replied below

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

Ultrawipf, 2022-03-06:
Thanks for reminding me to check the library versions, should have tried that before.
Downgrading the hub75 library from 2.0.7 to 2.0.5 actually fixed it so there did something change in the newer versions it seems.

Still need to do some debugging of sampling and FFT later but at least i get adc samples and a smooth fire animation.

I would like to switch to add an alternate mode with wifi support which does not have to run at the same time as the ADC if there are conflicts. Mostly for remotely displaying messages/graphics or possibly even video via a simple protocol.
Would you be interested in such features as well?

Regarding the power supply using 5V for the amplifier section might be helpful to get the best performance. But still i would leave out the LDO for the led supply.

Anyways nice project :) I see that you already put in a lot of work and it has a lot more potential as well.

Closed 2022-03-09.

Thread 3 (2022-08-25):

Error 'adc_gpio_init' was not declared in this scope

flasher69, 2022-08-25:
Hi guys,

when I try to compile the code in Arduino IDE and VS/PlatformIo I get this error message:

´´´
~~~~~~~~~~~~~~~~~~~~~~~~~~~~~~~~~~~~~~~~~~~~~~~~~~~~~~~~~~~~~~~~~~~~~~~~~~~~~~~
In file included from C:\Users\amira\OneDrive\Documents\libraries\FFT_EPS32_V1.0\FFT_EPS32_V1.0.ino:56:
C:\Users\amira\OneDrive\Documents\libraries\FFT_EPS32_V1.0\I2SPLUGIN.h: In function 'void setupI2S()':
I2SPLUGIN.h:52:8: error: 'adc_gpio_init' was not declared in this scope
  err = adc_gpio_init(ADC_UNIT_1, ADC_CHANNEL_0); //step 1
        ^~~~~~~~~~~~~
C:\Users\amira\OneDrive\Documents\libraries\FFT_EPS32_V1.0\I2SPLUGIN.h:52:8: note: suggested alternative: 'gpio_init'
  err = adc_gpio_init(ADC_UNIT_1, ADC_CHANNEL_0); //step 1
        ^~~~~~~~~~~~~
        gpio_init
exit status 1
'adc_gpio_init' was not declared in this scope
´´´

I don't really understand what is missing there. Any ideas?

Thank you

donnersm, 2022-08-25:
looks like you renamed some files. Try downloading the zip file from github again, unpack it to a blank folder and run the sketch unmodified from there.
Also make sure you are using the same libary versions as i did. version numbers are in the manual

flasher69, 2022-08-25:
when I try to open FFT_EPS32_V1.0.ino in Arduino IDE I get an error that the folder needs to have the same name as the ino file itself (currently it is in  C:\Users\me\OneDrive\Documents\libraries\FFT_ESP32_Analyzer-main\Main Sketch\V1.0) and I cannot open it unless I create a folder with the same name as the ino file (that's why I had to rename the V1.0)
I've checked the libraries and they are all the same versions as you've suggested it in your manuall.

donnersm, 2022-08-25:
rduino IDE I get an error that the folder needs to have the same name as/......allow it to b renamed but after, move the other files from the zip like I2SPLUGIN.h to same folder.

flasher69, 2022-08-25:
I tried what you've suggested but unfortunately same results. and same code error.
The webinstaller did work though. I will try it with WS2812 next days since I don't have anymore of them laying around.
Thank you Mark for your help

flasher69, 2022-08-27:
Hi Mark,
I've tired a bit and this issue seems be caused by Arduino IDE iteself (or maybe my PC?!). Anyway I've installed another older version of Arduino IDE (1.18.13) on a different PC and suddenly I don't get this error anymore!
Anyway thank you for your help  :)

jeurgenK, 2022-08-30:
The Problem is the espressif Version 5.1.1. With the espressif Version 3.5.0 is no Problem.
Mfg
Jürgen

flasher69, 2022-08-30:
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

Danke Jürgen. Das ist gute Hinweis :)

Thanx a lot

jeurgenK, 2022-09-02:
Hi,
that's how it would work. The version number is specified in the platformio.ini.

[env:esp32dev]
platform = espressif32@^3.5.0

With best regards from Cologne
Juergen

flasher69, 2022-09-04:
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

Thank you Juergen. That really solved the issue but I also had to change the Adafruit GFX Library version 1.11.3. After that I had no issues with the compiling.

Thanx again for all your helps guys.

cheers

Aggebitter, 2023-04-25:
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

https://www.esp32.com/viewtopic.php?t=25244

jeurgenK, 2024-01-15:
Hi houstontang,
adc_gpio_init is no longer needed and can be deleted.
I use the espressif PLATFORM:
Espressif 32 (6.4.0) > Espressif ESP32 Dev Modules.
I hope I could help you.

houstontang, 2024-01-15:
hi JeurgenK:
    thanks for your reply! I'm using an ESP32 Dev module as well, the SDK I have is ESP32 2.03, but I couldn't finish compiling on my side using Arduino IDE, can you please share me a workable package?  my personal email: tanghq8181@qq.com,
by the way, do you need  "driver/i2s.h" and "driver/adc.h" file which are included in "I2SPLUGIN.h" file.  thanks!

Houston

houstontang, 2024-01-15:
Jeurgenk, now I got you that you're using vscode+platfromIO, and using espressif32 6.4.0, while I'm using Arduino IDE, in the github package, the main sketch file v1.0.ino is still arduino format, did you just change it to .cpp and then use platfromIO? can you share me the PIO package via tanghq8181@qq.com? thanks a lot!

tanghq8181, 2024-01-15:
when I tried to compile the package, it will display"include/I2SPLUGIN.h:53:8: error: 'adc_gpio_init' was not declared in this scope" no matter I use Arduino IDE or PlatfromIO, if I disable below code, the compiling can be done, but I'm not sure if function is ok:
 /*
 err = adc_gpio_init(ADC_UNIT_1, ADC_CHANNEL_0); //step 1
  if (err != ESP_OK) {
    Serial.printf("Failed setting up adc channel: %d\n", err);
    while (true);
  }

 err = adc_gpio_init(ADC_UNIT_1, ADC_CHANNEL_3); //step 1
  if (err != ESP_OK) {
    Serial.printf("Failed setting up adc channel: %d\n", err);
    while (true);
  }
*/

jeurgenK, 2024-01-15:
OK,
i have Arduino IDE 2.2.1

my include 👍
#include <driver/i2s.h>
#include <driver/adc.h>

Message from Arduino IDE 👎
Using board 'esp32' from platform in folder: C:\Users\admin\AppData\Local\Arduino15\packages\esp32\hardware\esp32\2.0.14
Using core 'esp32' from platform in folder: C:\Users\admin\AppData\Local\Arduino15\packages\esp32\hardware\esp32\2.0.14

you need the libs:
 WebServer.h in Version 2.0.0
 WebSockets in Version 2.3.7
please, look at github.

Please check this.

by from Cologne

houstontang, 2024-01-16:
one more maybe last question for this issue, if you mark/disable below adc_gpio_init code, is the function normal? if you didn't mark/disable below adc_gpio_init code, do you get similar error message ( error: 'adc_gpio_init' was not declare)? thanks!
============

/*
err = adc_gpio_init(ADC_UNIT_1, ADC_CHANNEL_0); //step 1
if (err != ESP_OK) {
Serial.printf("Failed setting up adc channel: %d\n", err);
while (true);
}

err = adc_gpio_init(ADC_UNIT_1, ADC_CHANNEL_3); //step 1
if (err != ESP_OK) {
Serial.printf("Failed setting up adc channel: %d\n", err);
while (true);
}

jeurgenK, 2024-01-22:
Hallo  houstontang,
I can't say much about the Arduinio program because I use Visual Studio Code. I would definitely switch to Visual Studio Code. Simplifies programming and costs nothing.
I have no problem compiling with VS Code. Check Google for installation. There are enough videos there.

Have a nice day
J. Kommos

bungalit, 2024-05-21:
If you get a compilation error saying "adc_gpio_init" is not declared, it is because the function is now deprecated.
Fix the error by adding:
#include <driver/adc_deprecated.h>
to the file I2SPLUGIN.h

Thank you very much to the author for this project!
Good luck to all!

jeurgenK, 2024-05-21:
Hello, this problem 'adc_gpio_init' occurs when using ***@***.***

From the version ***@***.***, 'adc_gpio_init' can be omitted as this is no longer supported.

Best regards

J.K.

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

jeurgenK, 2024-05-21:
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

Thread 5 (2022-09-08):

Line in Problem

jeurgenK, 2022-09-08:
Hello,
I have a problem connecting to the output of my mixer. I can't get a reasonable level to drive the ESP32's input. Attempts to switch on a preamp brought no result. The proposed line circuit needs too high a level. What should I do ?
With the MIC MAX4466 there is no problem. But I don't want to use a MIC.

That was unsuccessful.
https://de.aliexpress.com/item/32960059477.html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

That was unsuccessful. I had tried several preamps.

Kind regards
J.Kommos

donnersm, 2022-09-09:
What is your audio source? When the problem occurs, is your usb plugged in to microcontroller?
did u adjust the potmeter for the line input to the correct level?  Send me some photos if the setup, the pcb top and bottom side. Whatsapp +31651875108

jeurgenK, 2022-09-09:
Hi Mark,
Thank you very much for your quick reply. I'll put together some photos and send them over. It's just a test setup for me. I haven't ordered the original yet because it comes from England and takes a long time. But I will still order.

Best regards from Cologne
Juergen

donnersm, 2022-09-09:
England? I live in holland and i ship from holland lol

Verstuurd vanaf mijn iPhone

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

jeurgenK, 2022-09-09:
When ordering, I am offered England ? Or did I look wrong?

jeurgenK, 2022-09-09:
Sorry, that was my fault. I had a different circuit board in mind.

jeurgenK, 2022-09-09:
Hi Mark,
The project is great. I also tested this with 64*16 LED. Just beautiful. The circuit corresponds to the circuit diagram. I will then order this board and then I will check it on the original board. I don't know how long the order will take? I ordered another circuit board. Just take a look.

New trial.I hope this solves my problem.
https://de.elv.com/elv-aufhol-verstaerker-ahv-100-komplettbausatz-ohne-gehaeuse-056393

Kind regards
Juergen

jeurgenK, 2022-09-09:
Hello Mark,
I will try the tests you suggested.
Juergen

jeurgenK, 2022-09-09:
Hi Mark,
this shows up when doing a test with the calibration. Is that right ?

BandCalibration_XXXX[64]=
{ 17.50, 1.19, 1.00, 1.18, 3.85, 4.17, 4.32, 6.25, 6.60, 3.30, 3.57, 3.65, 6.14, 5.38, 9.72, 13.46, 21.88, 4.86, 3.40, 10.00, 38.89, 20.59, 19.44, 31.82, 6.48, 4.73, 2.82, 3.68, 14.00, 50.00, 29.17, 5.56, 5.15, 7.29, 10.61, 29.17, 38.89, 116.67, 175.00, 26.92, 17.50, 10.61, 58.33, 4.93, 10.94, 6.25, inf, 350.00, inf, 175.00, 38.89, 70.00, 175.00, inf, 10.61, 5.07, 87.50, 9.46, inf, 350.00, inf, inf, inf, inf };

donnersm, 2022-09-10:
It shows inf on some channels , so the input noice on that channel is not good. Are you using a noice source to do this

Verstuurd vanaf mijn iPad

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

jeurgenK, 2022-09-10:
Hello Mark,
Yes, the noise was generated with the Adacity program and fed to the FFT with the Symsung S10.

donnersm, 2022-09-10:
Thats not a good noise source… the bandwith of phone and tabled is limited. Btw no need to recalibrate…i ment just activate it in normal mode . See the manual on how to do that… its something like double press on of the buttons

jeurgenK, 2022-09-10:
HiMark,

first of all thank you for your support. I will now do the tests again with HIFI Equitment. You have to know all that first. Once again, thank you very much for your help.

Kind regards
Juergen

flasher69, 2022-09-14:
Hi Juergen,

I also had to connect directly to an amp. From low sound sources such as a phone I had no luck getting it to work.
You need also to adjust the R23/R9 a lot until you get it right.

jeurgenK, 2022-09-25:
Hi flasher69,
thank you very much for your help.

Closed 2022-09-25.

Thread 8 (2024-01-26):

Channels <> Bins

alidaf, 2024-01-26:
I found this while looking for an ESP32 alternative to my Teensy-based dual channel analyser but was thrown when I realised that when you say 8-64 channels, you actually mean 8-64 bins or frequency bands. At least from an audio perspective, channels refers to the number of simultaneous inputs that can be processed.
Given the power of the ESP32, could it handle 2 simultaneous, multi-threaded transforms or is Teensy the only real option? I've been looking at the RPi Pico, which can handle ADC reads far quicker than anything else I've found, but I'm not sure about it's ability to handle the FFT,or even FHT for that matter.

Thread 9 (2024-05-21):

Problem with display on the P5 32 x 64 matrix

bungalit, 2024-05-21:
There's a problem. I use a P5 32 x 64 matrix. For all screen options 8, 16, 32 stripes, the leftmost strip is divided in half and one part is displayed on the left and the second part on the right. I don’t understand how to solve it. Who knows, tell me?

bungalit, 2024-05-25:
Solution found:
In my case, it was necessary to change these parameters to suit my P5 matrix
to the LEDDRIVER.h file
  mxconfig.driver = HUB75_I2S_CFG::FM6126A;
  mxconfig.clkphase = false;

Now everything works!

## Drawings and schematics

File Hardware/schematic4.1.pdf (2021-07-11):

12V/4A

## Gnd

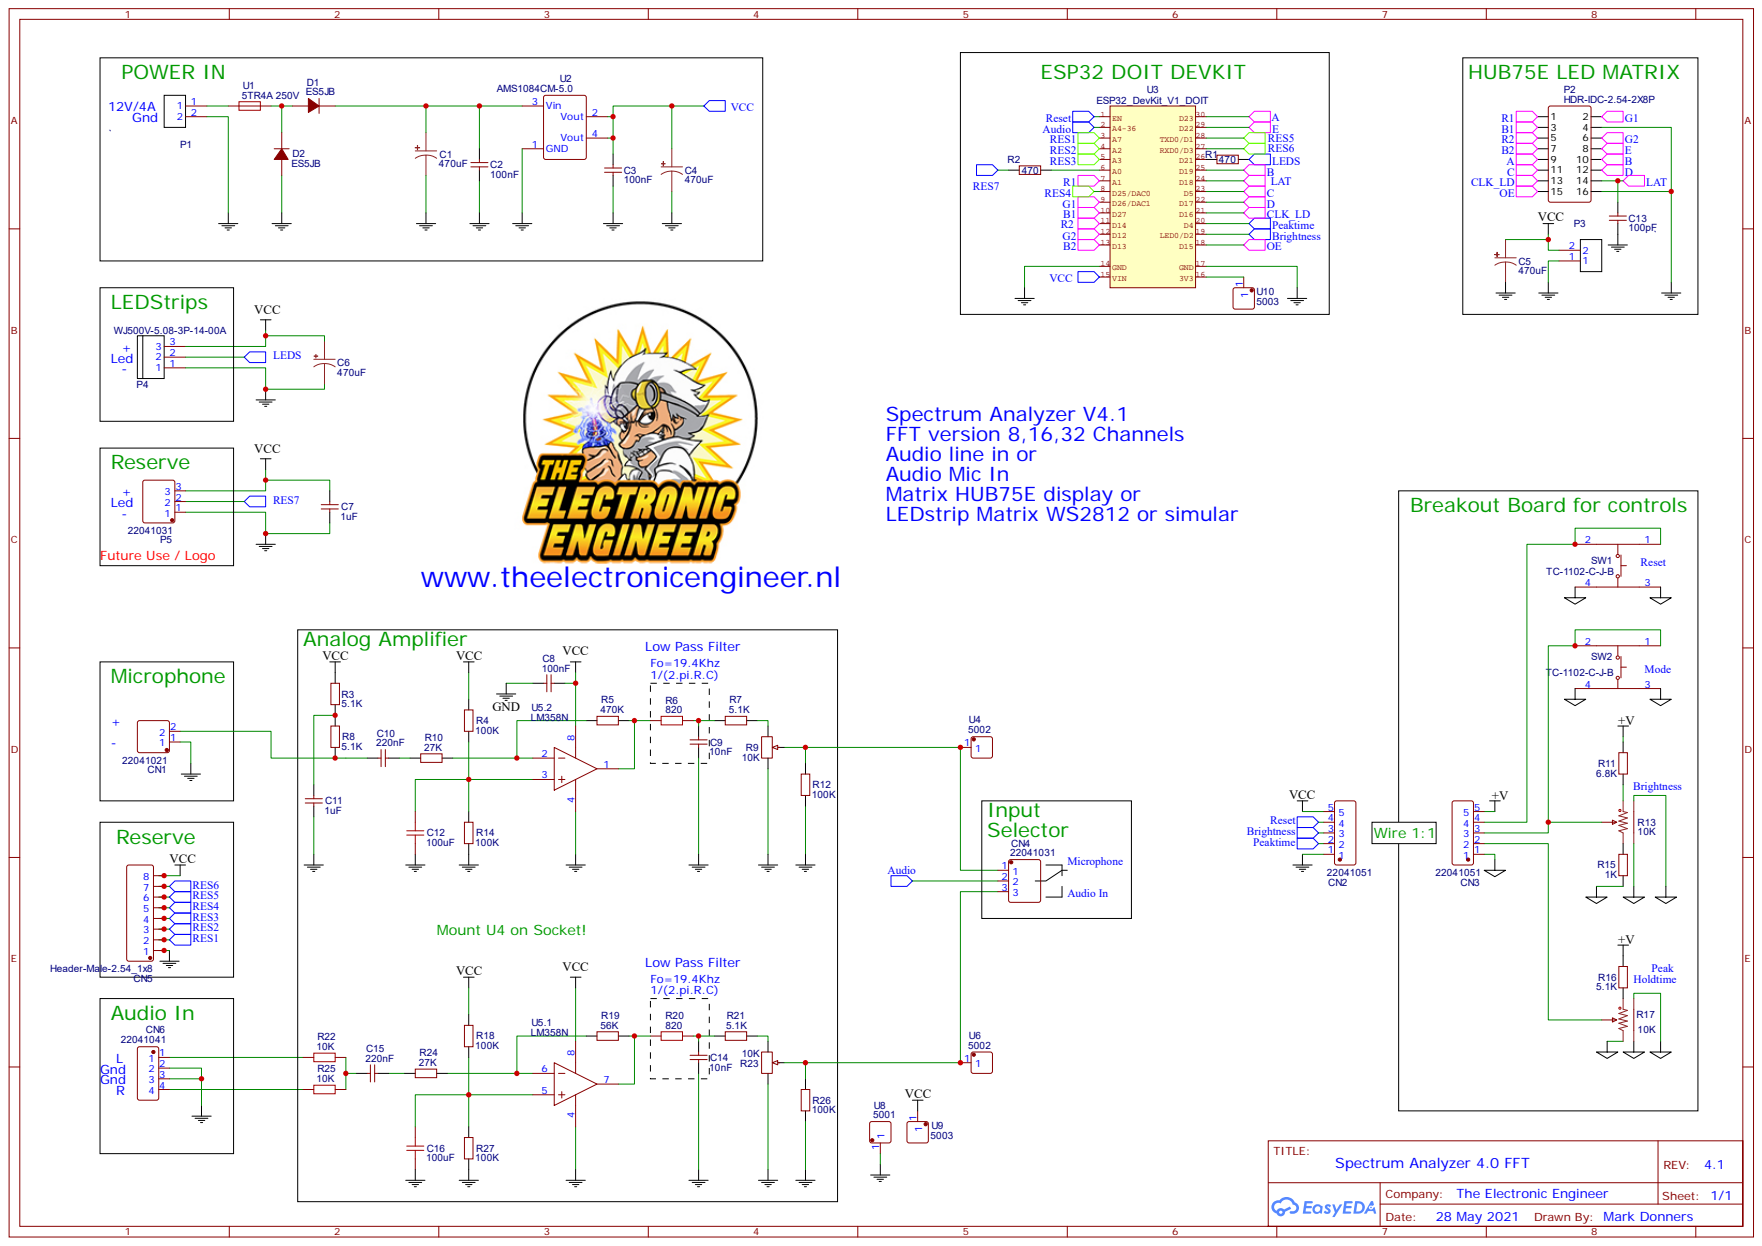
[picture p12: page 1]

Spectrum Analyzer V4.1
FFT version 8,16,32 Channels
Audio line in or
Audio Mic In
Matrix HUB75E display or
LEDstrip Matrix WS2812 or simular

Breakout Board for controls

TITLE: Spectrum Analyzer 4.0 FFT | REV: 4.1

Company: The Electronic Engineer | Sheet: 1/1

Drawn By: Mark Donners

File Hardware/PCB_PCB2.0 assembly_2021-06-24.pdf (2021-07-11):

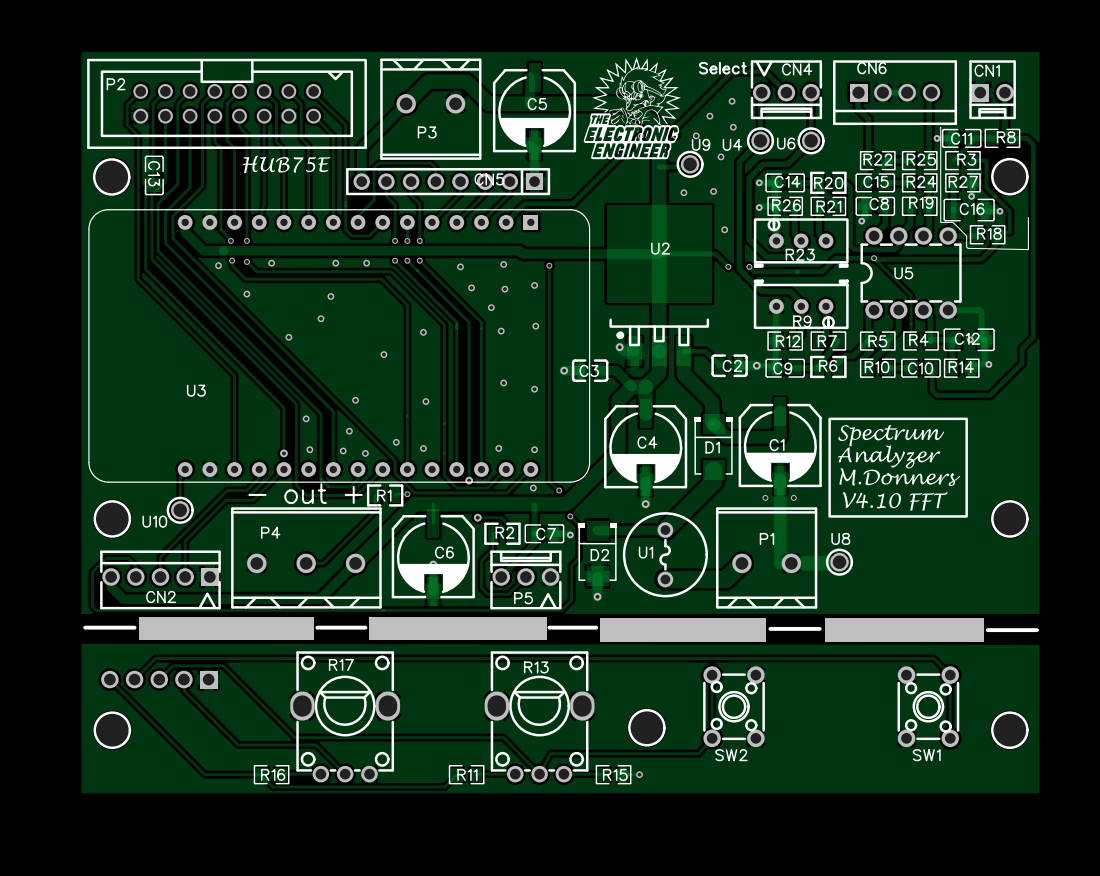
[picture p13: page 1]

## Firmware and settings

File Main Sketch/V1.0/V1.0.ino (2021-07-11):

 /********************************************************************************************************************************************************
 *                                                                                                                                                       *
 *  Project:         FFT Spectrum Analyzer                                                                                                               *
 *  Target Platform: ESP32                                                                                                                               *
 *                                                                                                                                                       * 
 *  Version: 1.0                                                                                                                                         *
 *  Hardware setup: See github                                                                                                                           *
 *  Spectrum analyses done with analog chips MSGEQ7                                                                                                      *
 *                                                                                                                                                       * 
 *  Mark Donners                                                                                                                                         *
 *  The Electronic Engineer                                                                                                                              *
 *  Website:   www.theelectronicengineer.nl                                                                                                              *
 *  facebook:  https://www.facebook.com/TheelectronicEngineer                                                                                            *
 *  youtube:   https://www.youtube.com/channel/UCm5wy-2RoXGjG2F9wpDFF3w                                                                                  *
 *  github:    https://github.com/donnersm                                                                                                               *
 *                                                                                                                                                       *  
 ********************************************************************************************************************************************************* 
 * Version History                                                                                                                                       *
 *  1.0 First release, code extraced from 14 band spectrum analyzer 3.00 and modified to by used with FFT on a ESP32. No need for frequency board or     *
 *      MCGEQ7 chips.                                                                                                                                    *
 *      - HUB75 interface or                                                                                                                             *
 *      - WS2812 leds ( matrix/ledstrips)                                                                                                                *
 *      - 8/16/32 or 64 channel analyzer                                                                                                                 *
 *      - calibration for White noise, pink noise, brown noise sensitivity included and selectable                                                         *
 *      - Fire screensaver                                                                                                                               *
 *      - Display of logo and interface text when used with HUB75                                                                                        *
 *                                                                                                                                                       *
 *********************************************************************************************************************************************************
 * Version FFT 1.0 release July 2021                                                                                                                     *
 *********************************************************************************************************************************************************
 *  Status   | Description                                                                                                                               *
 *  Open     | Some Hub75 displays use a combination of chipsets of are from a different productions batch which will not work with this libary          *
 *  Open     | Sometime the long press for activating/de-activating the autoChange Pattern mode doesn't work                                             *
 *  Solved   | When using 64 bands, band 0 is always at max value. This was caused by the array dize [64]-> solved by chnaging it to 65                  *
 * Not a bug | Different types of HUB75 displays require different libary settings.It is what it is and it all depends on what the distributer sends you.*
 *           | For into on the libary settings, see the library documentation on Github: https://github.com/mrfaptastic/ESP32-HUB75-MatrixPanel-I2S-DMA  *
 * Wish      | Web interface. not possible without some heavy workaround cant use WIFI and ADC at same time                                              *
 * *******************************************************************************************************************************************************          
 * People who inspired me to do this build and figure out how stuff works:
 * Dave Plummer         https://www.youtube.com/channel/UCNzszbnvQeFzObW0ghk0Ckw
 * Mrfaptastic          https://github.com/mrfaptastic
 * Scott Marley         https://www.youtube.com/user/scottmarley85
 * Brian Lough          https://www.youtube.com/user/witnessmenow
 * atomic14             https://www.youtube.com/channel/UC4Otk-uDioJN0tg6s1QO9lw
 * 
 * Make sure your arduino IDE settings: Compiler warnings is set to default to make sure the code will compile                                           */





#define VERSION     "V1.0"

#include <FastLED_NeoMatrix.h>
#include <arduinoFFT.h>
#include "I2SPLUGIN.h"
#include <math.h>
#include <ESP32-HUB75-MatrixPanel-I2S-DMA.h>
#include "FFT.h"
#include "LEDDRIVER.H"
#include "Settings.h"
#include "PatternsHUB75.h"
#include "PatternsLedstrip.h"                            
#include "fire.h"
#include "logos.h"
int skip=true;
int ButtonOnTimer=0;
int ButtonStarttime=0;
int ButtonSequenceCounter=0;
int ButtonOffTimer=0;
int ButtonStoptime=0;

int ButtonPressedCounter=0;
int ButtonReleasedCounter=0;
int ShortPressFlag=0;
int LongPressFlag=0;
int LongerPressFlag=0;
boolean Next_is_new_pressed= true;
boolean Next_is_new_release = true;
int PreviousPressTime=0;
#define up  1
#define down 0
int PeakDirection=0;

long LastDoNothingTime = 0;                       // only needed for screensaver
int DemoModeMem=0;                                   // to remember what mode we are in when going to demo, in order to restore it after wake up
bool AutoModeMem=false;                                // same story
bool DemoFlag=false;                               // we need to know if demo mode was manually selected or auto engadged. 

char LCDPrintBuf[30];



void setup() {
 Serial.begin(115200);
 Serial.println("Setting up Audio Input I2S");
 setupI2S();
 Serial.println("Audio input setup completed");
 delay(1000);
 #ifdef Ledstrip
  SetupLEDSTRIP();
 #endif  

 #ifdef HUB75
  SetupHUB75();
  if (kMatrixHeight>60){
  dma_display->setBrightness8(100);
  #if LogoBoot 
   drawLogo();
   delay(2500);
  #endif 
  }
 #endif
 
 
}

void loop() {
 size_t bytesRead = 0;
 int TempADC=0;
 if (skip==false)i2s_adc_disable(I2S_NUM_0);
 skip=false; // we only want to skip this the very first loop run.

 //Handle Userinterface
 {
  // set brightness and test if button is pressed
  TempADC = analogRead(BRIGHTNESSPOT);

  if (TempADC<10){ // ADC value < 10 so button is pressed
    ButtonOffTimer=0;
    ButtonOnTimer=millis()-ButtonStarttime;
    ButtonStoptime=millis();
  }
  else { // no Button pressed so ADC value is not related to button and can be proccessed
  ButtonOnTimer=0;
  ButtonOffTimer=millis()-ButtonStoptime;
  ButtonStarttime = millis();
  
  // read potmeters and process
  Peakdelay=map(analogRead(PEAKDELAYPOT),0,4095,1,100);
  BRIGHTNESSMARK=map(TempADC,100,2100,BRIGHTNESSMIN,BRIGHTNESSMAX);
// dbgprint("potm:%d",BRIGHTNESSMARK);
  #ifdef Ledstrip
    FastLED.setBrightness(BRIGHTNESSMARK);
  #endif
  #ifdef HUB75
    dma_display->setBrightness8(map(TempADC,100,2100,BRIGHTNESSMIN,BRIGHTNESSMAX));

   #endif
  }
 
 
  if(ButtonOffTimer>ButtonTimeout){
    ButtonStoptime=millis(); // time that no switch was presset will reset the counter.
    ButtonSequenceCounter=0; // reset the sequencecounter
    if (ShortPressFlag==1){
     // Serial.printf("Short press detected\n");
      buttonPushCounter = (buttonPushCounter + 1) % 13;
      #ifdef HUB75
      dma_display->clearScreen();
      #endif
      Serial.printf("Pattern Mode changed to: %d\n",buttonPushCounter);
      ShortPressFlag=0;
    }
  }
  if ((ButtonOnTimer>LongerPress)&&(ButtonOnTimer<(LongerPress+ShortPress))){LongerPressFlag=1;}
  else if  ((ButtonOnTimer>LongPress)&&(ButtonOnTimer<(LongPress+ShortPress))){LongPressFlag=1;}
  else if ((ButtonOnTimer>ShortPress)&&(ButtonOnTimer<(2*ShortPress))){
    ShortPressFlag=1;
    if((millis()-PreviousPressTime)<ButtonSequenceRepeatTime){
      ButtonSequenceCounter++;
      dbgprint("Multible press counter: %d\n",ButtonSequenceCounter);
      ShortPressFlag=0;
      CalibrationType= (CalibrationType +1)% 4;
      Serial.printf("Calibration table changed to: %s\n",Filtername[CalibrationType]);
      
      sprintf(LCDPrintBuf,"Cal Filter: %s",Filtername[CalibrationType]);
      DisplayPrint(LCDPrintBuf);
      
    }
    PreviousPressTime=millis();
  }
  if (LongerPressFlag==1){ 
    dbgprint( "Longer press detected\n");
    autoChangePatterns = !autoChangePatterns;
    if(autoChangePatterns == true){ 
      Serial.print("Patterns wil now change every few seconds\n");
      DisplayPrint((char*) "Autochange ON");
    }
    else {
      Serial.print("Automatically changing of pattern is now disabled\n");
      DisplayPrint((char*) "Autochange OFF");
    }
    LongerPressFlag=0;
    ShortPressFlag=0;
  } 
  else if (LongPressFlag==1){
    dbgprint("long press detected\n");
    autoChangePatterns = !autoChangePatterns;
    if(autoChangePatterns == true){ 
      Serial.print("Patterns wil now change every few seconds\n");
      DisplayPrint((char*) "Autochange ON");
    }
    else {
      Serial.print("Automatically changing of pattern is now disabled\n");
      DisplayPrint((char*)"Autochange OFF");
    }
    LongPressFlag=0;
    ShortPressFlag=0;
  }
 } // end user interface


  //############ Step 1: read samples from the I2S Buffer ##################
 i2s_adc_enable(I2S_NUM_0);

 i2s_read(I2S_PORT, 
         (void*)samples, 
          sizeof(samples),  
          &bytesRead,   // workaround This is the actual buffer size last half will be empty but why?
          portMAX_DELAY); // no timeout

 if (bytesRead != sizeof(samples)){
   Serial.printf("Could only read %u bytes of %u in FillBufferI2S()\n", bytesRead, sizeof(samples));
   // return;
 }

 //############ Step 2: compensate for Channel number and offset, safe all to vReal Array   ############
 for (uint16_t i = 0; i < ARRAYSIZE(samples); i++) {
   vReal[i] = offset-samples[i];
   vImag[i] = 0.0; //Imaginary part must be zeroed in case of looping to avoid wrong calculations and overflows
   #if PrintADCRAW
    Serial.printf("%7d,",samples[i]); 
   #endif

   #if VisualizeAudio
    Serial.printf("%d\n",samples[i]);
   #endif
  }
 
   #if PrintADCRAW
    Serial.printf("\n"); 
   #endif

 //############ Step 3: Do FFT on the VReal array  ############
  // compute FFT
  FFT.DCRemoval();
  FFT.Windowing(vReal, SAMPLEBLOCK, FFT_WIN_TYP_HAMMING, FFT_FORWARD);
  FFT.Compute(vReal, vImag, SAMPLEBLOCK, FFT_FORWARD);
  FFT.ComplexToMagnitude(vReal, vImag, SAMPLEBLOCK);
  FFT.MajorPeak(vReal, SAMPLEBLOCK, samplingFrequency); 
  for (int i = 0; i < numBands; i++) {
    FreqBins[i] = 0;
  }
 //############ Step 4: Fill the frequency bins with the FFT Samples ############
 float averageSum = 0.0f;
 for (int i = 2; i < SAMPLEBLOCK / 2; i++){ 
   averageSum+=vReal[i];
   if (vReal[i] > NoiseTresshold){
     int freq = BucketFrequency(i);
     int iBand = 0;
     while (iBand < numBands){
       if (freq < BandCutoffTable[iBand])break;
       iBand++;
     }
     if (iBand > numBands)iBand = numBands;
     FreqBins[iBand]+= vReal[i]; 
     //  float scaledValue = vReal[i];
     //  if (scaledValue > peak[iBand])
     //    peak[iBand] = scaledValue;
   }
 }

// bufmd[0]=FreqBins[12];
 #if PrintRAWBins
  for ( int y=0; y<numBands;y++){
    Serial.printf("%7.1f,",FreqBins[y]);
  }
  Serial.printf("\n");
 #endif
  
 //############ Step 5: Determine the VU value  and mingle in the readout...( cheating the bands ) ############ Step 
 float t=averageSum / (SAMPLEBLOCK / 2);
 gVU = max(t, (oldVU * 3 + t) / 4);
 oldVU = gVU; 
 if(gVU>DemoTreshold)LastDoNothingTime = millis(); // if there is signal in any off the bands[>2] then no demo mode

  // Serial.printf("gVu: %d\n",(int) gVU);

 for(int j=0;j<numBands;j++){
   if (CalibrationType==1)FreqBins[j]*= BandCalibration_Pink[j];
   else if (CalibrationType==2)FreqBins[j]*= BandCalibration_White[j];
    else if (CalibrationType==3)FreqBins[j]*= BandCalibration_Brown[j];

 }



 //*
 //############ Step 6: Averaging and making it all fit on screen 
 //for (int i = 0; i < numBands; i++) {
   //Serial.printf ("Chan[%d]:%d",i,(int)FreqBins[i]);
    //FreqBins[i] = powf(FreqBins[i], gLogScale); // in case we want log scale..i leave it in here as reminder
   //  Serial.printf( " - log: %d \n",(int)FreqBins[i]);
// }
 static float lastAllBandsPeak = 0.0f;
 float allBandsPeak = 0;
 //bufmd[1]=FreqBins[13];
 //bufmd[2]=FreqBins[1];
 for (int i = 0; i < numBands; i++){
   //allBandsPeak = max (allBandsPeak, FreqBins[i]);
   if (FreqBins[i]> allBandsPeak){
     allBandsPeak = FreqBins[i];
   }
 }   
 if (allBandsPeak < 1)allBandsPeak = 1;
 //  The followinf picks allBandsPeak if it's gone up.  If it's gone down, it "averages" it by faking a running average of GAIN_DAMPEN past peaks
 allBandsPeak = max(allBandsPeak, ((lastAllBandsPeak * (GAIN_DAMPEN-1)) + allBandsPeak) / GAIN_DAMPEN);  // Dampen rate of change a little bit on way down
 lastAllBandsPeak = allBandsPeak;


 if (allBandsPeak < 80000)allBandsPeak = 80000;
 for (int i = 0; i < numBands; i++){ 
   FreqBins[i] /= (allBandsPeak * 1.0f);
 }

 // Process the FFT data into bar heights
 for (int band = 0; band < numBands; band++) {
   int barHeight = FreqBins[band]*kMatrixHeight-1;  //(AMPLITUDE);
   if (barHeight > TOP-2) barHeight = TOP-2;
  
   // Small amount of averaging between frames
   barHeight = ((oldBarHeights[band] * 1) + barHeight) / 2;

   // Move peak up
   if (barHeight > peak[band]) {
     peak[band] = min(TOP, barHeight);
     PeakFlag[band]=1;
   }
    bndcounter[band]+=barHeight; // ten behoeve calibratie

    // if there hasn't been much of a input signal for a longer time ( see settings ) go to demo mode
   if ((millis() - LastDoNothingTime) > DemoAfterSec && DemoFlag==false)
   { dbgprint("In loop 1:  %d", millis() - LastDoNothingTime);
    DemoFlag=true;
    // first store current mode so we can go back to it after wake up
    DemoModeMem=buttonPushCounter;
    AutoModeMem=autoChangePatterns;
    autoChangePatterns=false;
    buttonPushCounter=12;
    #ifdef HUB75
    dma_display->clearScreen();
    #endif
    dbgprint("Automode is turned of because of demo");
   } 
   // Wait,signal is back? then wakeup!     
    else if (DemoFlag==true &&   (millis() - LastDoNothingTime) < DemoAfterSec   )   
    { //("In loop 2:  %d", millis() - LastDoNothingTime);
      // while in demo the democounter was reset due to signal on one of the bars.
      // So we need to exit demo mode.
      #ifdef HUB75
      dma_display->clearScreen();
      #endif
      buttonPushCounter=DemoModeMem; // restore settings
      dbgprint ("automode setting restored to: %d",AutoModeMem);
      autoChangePatterns=AutoModeMem;// restore settings
      DemoFlag=false;  
    }
    #if BottomRowAlwaysOn
      if (barHeight==0)barHeight=1; // make sure there is always one bar that lights up
    #endif
  // Now visualize those bar heights
  switch (buttonPushCounter) {
    case 0:
     #ifdef HUB75
      PeakDirection=down;
      BoxedBars(band, barHeight);
      BluePeak(band);
     #endif
     #ifdef Ledstrip
      changingBarsLS(band, barHeight);
     #endif
     break;
     
    case 1: 
     #ifdef HUB75
      PeakDirection=down;
      BoxedBars2(band, barHeight);
      BluePeak(band);
     #endif 
     #ifdef Ledstrip
     TriBarLS(band, barHeight);
     TriPeakLS(band);
     #endif
     break;
    case 2:
     #ifdef HUB75
      PeakDirection=down;
      BoxedBars3(band, barHeight);
      RedPeak(band);
     #endif
     #ifdef Ledstrip
      rainbowBarsLS(band, barHeight);
      NormalPeakLS(band, PeakColor1);
     #endif
      break;
    case 3:
     #ifdef HUB75
      PeakDirection=down;
      RedBars(band, barHeight); 
      BluePeak(band);
     #endif
     #ifdef Ledstrip
      purpleBarsLS(band, barHeight);
      NormalPeakLS(band, PeakColor2);
     #endif
      break;
    case 4:
     #ifdef HUB75
      PeakDirection=down;
      ColorBars(band, barHeight);
     #endif
     #ifdef Ledstrip
      SameBarLS(band, barHeight); 
      NormalPeakLS(band, PeakColor3);
     #endif
      break;
    case 5:
     #ifdef HUB75
      PeakDirection=down;
      Twins(band, barHeight);
      WhitePeak(band);
     #endif
     #ifdef Ledstrip
      SameBar2LS(band, barHeight); 
      NormalPeakLS(band, PeakColor3);
     #endif
     break;
    case 6:
     #ifdef HUB75
      PeakDirection=down;
      Twins2(band, barHeight);
      WhitePeak(band);
     #endif
     #ifdef Ledstrip
      centerBarsLS(band, barHeight);
     #endif
      break;
    case 7:
     #ifdef HUB75
       PeakDirection=down;
      TriBars(band, barHeight);
      TriPeak(band);
     #endif
     #ifdef Ledstrip
      centerBars2LS(band, barHeight);
     #endif
      break;
    case 8:
     #ifdef HUB75 
      PeakDirection=up;
      TriBars(band, barHeight);
      TriPeak(band);
     #endif
     #ifdef Ledstrip
      centerBars3LS(band, barHeight);
     #endif
      break;
    case 9:
     #ifdef HUB75
     PeakDirection=down;
     centerBars(band, barHeight);
     #endif
     #ifdef Ledstrip
       BlackBarLS(band, barHeight);
       outrunPeakLS(band);
     #endif
     break;
    case 10:
     #ifdef HUB75
     PeakDirection=down;
     centerBars2(band, barHeight);
     #endif
     #ifdef Ledstrip
      BlackBarLS(band, barHeight);
      NormalPeakLS(band, PeakColor5);
     #endif
      break;
    case 11:
     #ifdef HUB75
      PeakDirection=down;
      BlackBars(band, barHeight);
      DoublePeak(band);     
     #endif
     #ifdef Ledstrip
      BlackBarLS(band, barHeight);
      TriPeak2LS(band);
     #endif
      break;
    case 12:
     #ifdef HUB75
      make_fire(); // go to demo mode
     #endif
     #ifdef Ledstrip
      matrix->fillRect(0, 0, matrix->width(), 1, 0x0000); // delete the VU meter
      make_fire();
     #endif
     break;
  } 
  
  // Save oldBarHeights for averaging later
  oldBarHeights[band] = barHeight;
 }
// for calibration
 //bndcounter[h]+=barHeight;
 if (loopcounter==256){
  loopcounter=0;
 #if CalibratieLog 
   Calibration();
   for(int g=0;g<numBands;g++)bndcounter[g]=0;
 #endif
 
 }
 loopcounter++;

 if (buttonPushCounter!=12) DrawVUMeter(0); // Draw it when not in screensaver mode
 
 #if PrintRAWBins
  Serial.printf("\n");
  //delay(10);
 #endif


  
   // Decay peak
 EVERY_N_MILLISECONDS(Fallingspeed){
   for (byte band = 0; band < numBands; band++){
     if(PeakFlag[band]==1){
       PeakTimer[band]++;
       if (PeakTimer[band]> Peakdelay){PeakTimer[band]=0;PeakFlag[band]=0;}
     }
     else if ((peak[band] > 0) &&(PeakDirection==up)){ 
       peak[band] += 1;
       if (peak[band]>(kMatrixHeight+10))peak[band]=0;
       } // when to far off screen then reset peak height
     else if ((peak[band] > 0)&&(PeakDirection==down)){ peak[band] -= 1;}
   }   
     colorTimer++;
 }

 
 EVERY_N_MILLISECONDS(10)colorTimer++; // Used in some of the patterns
 
 EVERY_N_SECONDS(SecToChangePattern) {
   // if (FastLED.getBrightness() == 0) FastLED.setBrightness(BRIGHTNESSMARK);  //Re-enable if lights are "off"
   if (autoChangePatterns){ 
    buttonPushCounter = (buttonPushCounter + 1) % 12;
    #ifdef HUB75
    dma_display->clearScreen();
    #endif
   }
 }

 
 #ifdef Ledstrip
  delay(1); // needed to give fastled a minimum recovery time
  FastLED.show();
 #endif
  
} // loop end






  // BucketFrequency
  //
  // Return the frequency corresponding to the Nth sample bucket.  Skips the first two 
  // buckets which are overall amplitude and something else.

int BucketFrequency(int iBucket){
 if (iBucket <= 1)return 0;
 int iOffset = iBucket - 2;
 return iOffset * (samplingFrequency / 2) / (SAMPLEBLOCK / 2);
}
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

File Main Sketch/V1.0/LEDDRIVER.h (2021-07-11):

 /********************************************************************************************************************************************************
 *                                                                                                                                                       *
 *  Project:         FFT Spectrum Analyzer                                                                                                               *
 *  Target Platform: ESP32                                                                                                                               *
 *                                                                                                                                                       * 
 *  Version: 1.0                                                                                                                                         *
 *  Hardware setup: See github                                                                                                                           *
 *  Spectrum analyses done with analog chips MSGEQ7                                                                                                      *
 *                                                                                                                                                       * 
 *  Mark Donners                                                                                                                                         *
 *  The Electronic Engineer                                                                                                                              *
 *  Website:   www.theelectronicengineer.nl                                                                                                              *
 *  facebook:  https://www.facebook.com/TheelectronicEngineer                                                                                            *
 *  youtube:   https://www.youtube.com/channel/UCm5wy-2RoXGjG2F9wpDFF3w                                                                                  *
 *  github:    https://github.com/donnersm                                                                                                               *
 *                                                                                                                                                       *  
 ********************************************************************************************************************************************************/
 

#pragma once
#include "Settings.h"
/* There are several options to display the data from the FFT.
 * 1. Use a ledstrip like WS2812 or simular
 * 2. Use a Hub75 display
 * 3. Using both is possible but not recommended because of the required speed.
 */

// select one of these and comment out the other
//#define Ledstrip
#define HUB75

//Panel settings change to match your setup
#ifdef HUB75
 #define PANEL_WIDTH            64
 #define PANEL_HEIGHT           64                  // Panel height of 64 will required PIN_E to be defined.
 #define PANELS_NUMBER          2                   // Number of chained panels, if just a single panel, obviously set to 1
 // only need to match panel settings above
 #define PANE_WIDTH PANEL_WIDTH * PANELS_NUMBER
 #define PANE_HEIGHT PANEL_HEIGHT
 const uint8_t kMatrixWidth =   PANEL_WIDTH * PANELS_NUMBER;                // Matrix width --> number of columns in your led matrix
 const uint8_t kMatrixHeight =  PANEL_HEIGHT;                 // Matrix height --> number of leds per column
#endif



// Ledstrip settings
#define CHIPSET         WS2812B                     // LED strip type
#define LED_PIN         21                          // LED strip data
//#define SERPENTINE     false                        // Set to false if you're LEDS are connected end to end, true if serpentine
#define COLOR_ORDER     GRB                         // If colours look wrong, play with this
#define LED_VOLTS       5                           // Usually 5 or 12
#define MAX_MILLIAMPS   2000                        // Careful with the amount of power here if running off USB port
#ifdef Ledstrip
 const uint8_t kMatrixWidth =32;//128;                    // Matrix width --> number of columns in your led matrix
 const uint8_t kMatrixHeight = 16;//64;                   // Matrix height --> number of leds per column
 #define PANE_WIDTH kMatrixWidth
#endif

#define BAR_WIDTH  (kMatrixWidth /(numBands ))  // If width >= 8 light 1 LED width per bar, >= 16 light 2 LEDs width bar etc
#define TOP            (kMatrixHeight - 0)         // Don't allow the bars to go offscreen
#define NeededWidth (BAR_WIDTH * numBands)           // we need this to see if all bands fit or that we have left over space
#define NUM_LEDS   (kMatrixWidth * kMatrixHeight)   // Total number of LEDs
CRGB leds[NUM_LEDS];

//***********************************************************************
// These are the settings for the Hub75 display
// pin settings, dont change unless you are using customized hardware
//***********************************************************************

#define A_PIN         23
#define B_PIN         19
#define C_PIN         5
#define D_PIN         17
#define E_PIN         22
#define LAT_PIN       18
#define OE_PIN        15
#define CLK_PIN       16
#define R1_PIN        33
#define B2_PIN        13
#define R2_PIN        14
#define G2_PIN        12
#define G1_PIN        26
#define B1_PIN        27

 
#ifdef HUB75
// placeholder for the matrix object
MatrixPanel_I2S_DMA *dma_display = nullptr;
#endif


// See manual if you need to change these settings
#ifdef Ledstrip
  // FastLED_NeoMaxtrix - see https://github.com/marcmerlin/FastLED_NeoMatrix for Tiled Matrixes, Zig-Zag and so forth
  FastLED_NeoMatrix *matrix = new FastLED_NeoMatrix(leds, kMatrixWidth, kMatrixHeight,
                                  NEO_MATRIX_BOTTOM        + NEO_MATRIX_RIGHT +
                                  NEO_MATRIX_COLUMNS       + NEO_MATRIX_ZIGZAG +
                                  NEO_TILE_TOP + NEO_TILE_LEFT + NEO_TILE_ROWS);

/* // this one is used if you are using a ledstrip setup simular to the one from the acryllic spectrum analyzer
  FastLED_NeoMatrix *matrix = new FastLED_NeoMatrix(leds, kMatrixWidth, kMatrixHeight,
                                  NEO_MATRIX_BOTTOM        + NEO_MATRIX_LEFT +
                                  NEO_MATRIX_COLUMNS       + NEO_MATRIX_PROGRESSIVE +
                                  NEO_TILE_TOP + NEO_TILE_LEFT + NEO_TILE_ROWS);
 */

#endif
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
